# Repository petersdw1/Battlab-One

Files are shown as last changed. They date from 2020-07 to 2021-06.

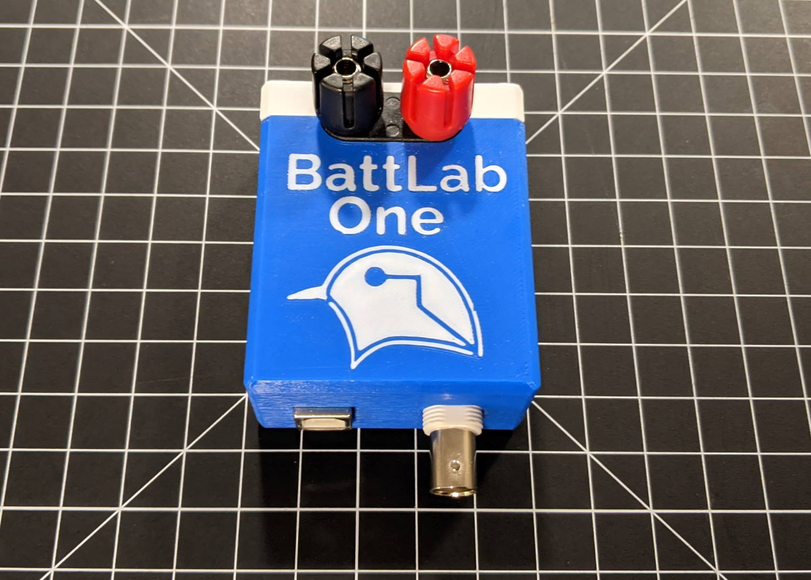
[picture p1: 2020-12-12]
3D_Printable_Enclosure/BattLab_One_Enclosure.jpg

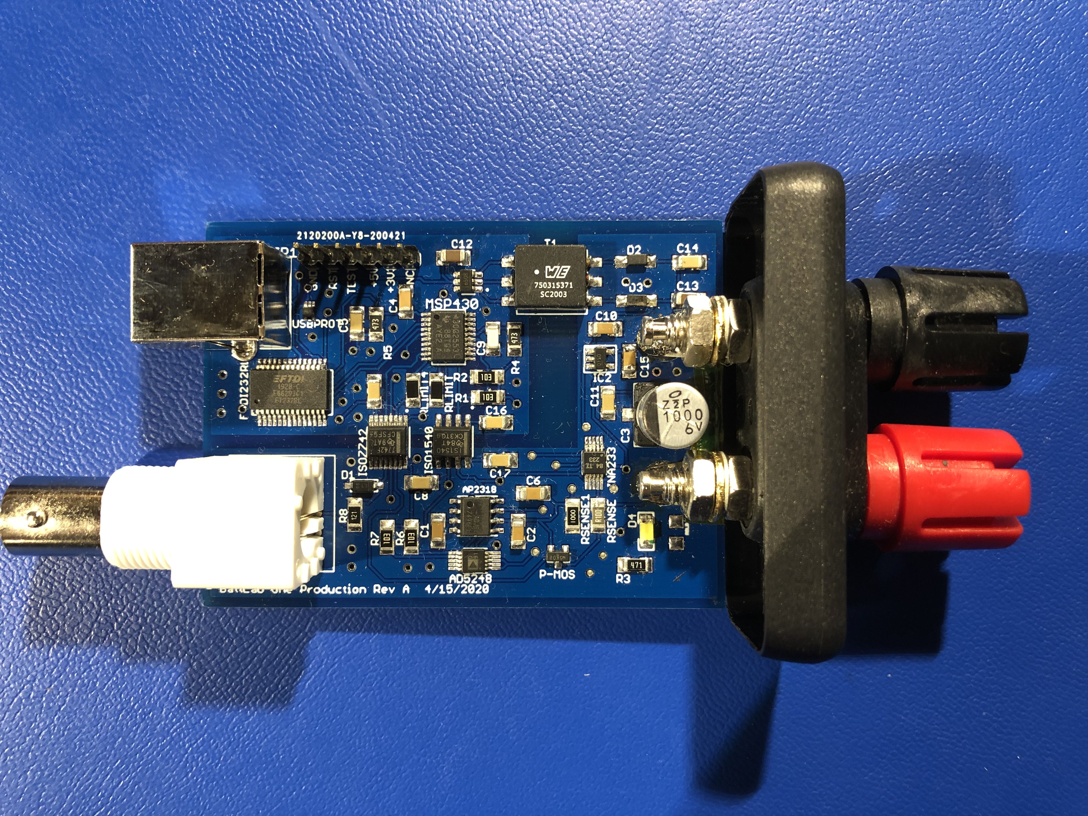
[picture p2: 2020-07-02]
Production_Rev_A_Board_Image.jpg

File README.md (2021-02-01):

# BattLab-One
A New Tool for Estimating and Optimizing Battery Life for Your Next Internet of Things Project

  - Battlab-One Quick Start Guide

  - BattLab_One_Production_Rev_A.py - Python Application Code for Production version 1.01

  - Production_Rev_A.sch - Schematic in Eagle

  - Production_Rev_A..brd - PCB Layout in Eagle

  - MSP430Firmware.c - Firmware code for the MSP430 for Production Version 1.01

  - BOM_Production_Rev_A - Bill of Materials for Battlab-One Production Rev A

  - 98-bluebird-labs.rules - Linux udev rules for Battlab-One

  See more at www.bluebird-labs.com
  
  

# Development

This project uses pipenv to take care of setting up a virtual environment as well as managing the dependencies needed.

1. Install pipenv as describe here https://pypi.org/project/pipenv/
2. Start a terminal and change to the root folder of this project.
3. Run pipenv to setup the environment: `pipenv install --dev`
4. Start the pipenv shell: `pipenv shell`
5. Start the application: `python BattLab_One_V1.0.6.py`

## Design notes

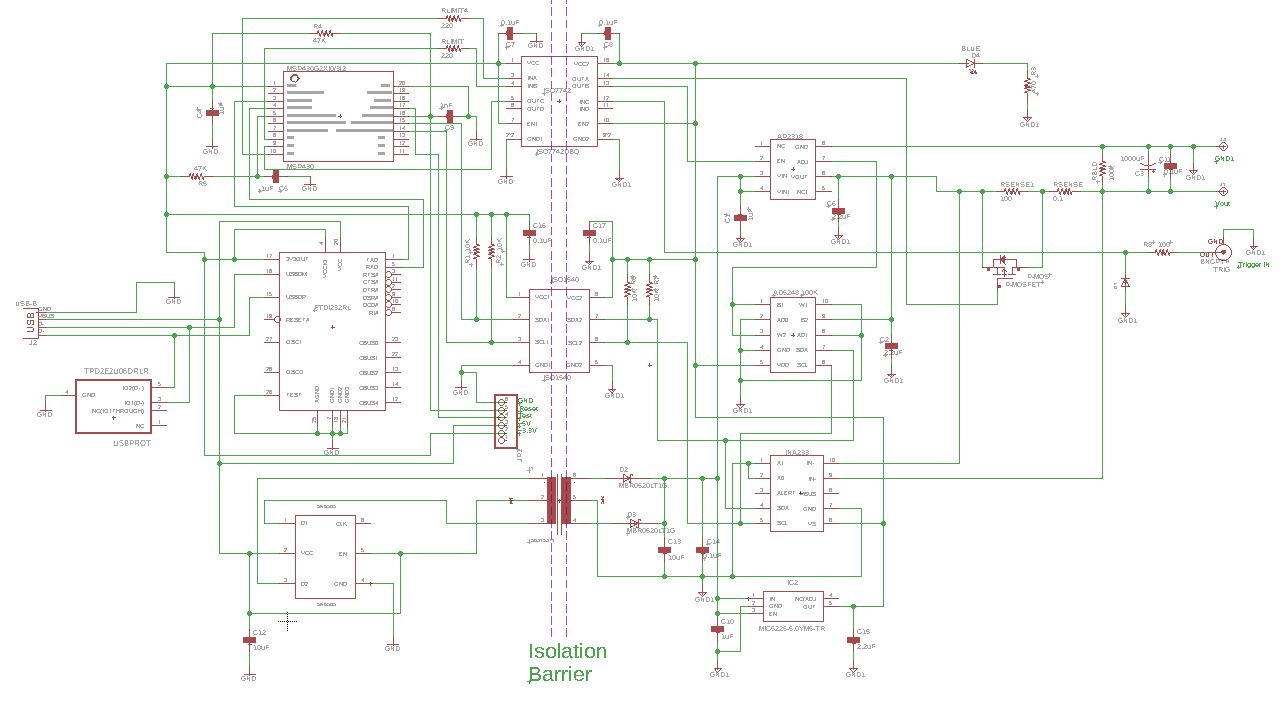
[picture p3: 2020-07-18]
Battlab_One_Schematic_Image.JPG

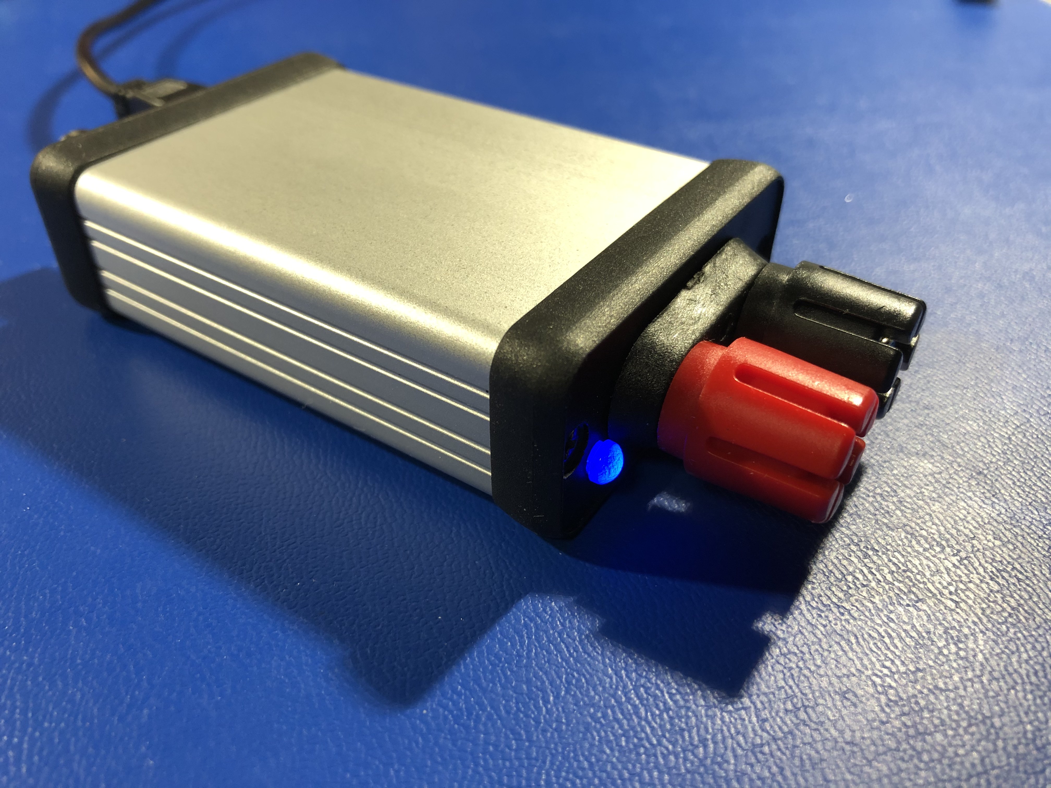
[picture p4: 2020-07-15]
Battlab_One.jpg

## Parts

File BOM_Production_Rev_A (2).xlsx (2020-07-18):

Part | Value | Device | Package | Description
AD5248 | 100K | AD5248 | MSOP-10 | Digital potentiometer
AP2318 |  | AP2318 | SOIC-8 | Voltage Regulator
C1 | 1uF | CAP1206 | 1206 | Capacitor
C2 | 2.2uF | CAP1206 | 1206 | Capacitor
C3 | 1000uF | CPOL-USF | PANASONIC_F | POLARIZED CAPACITOR
C4 | 1uF | CAP1206 | 1206 | Capacitor
C5 | .1uF | CAP1206 | 1206 | Capacitor
C6 | 2.2uF | CAP1206 | 1206 | Capacitor
C7 | 0.1uF | CAP1206 | 1206 | Capacitor
C8 | 0.1uF | CAP1206 | 1206 | Capacitor
C9 | 1nF | CAP1206 | 1206 | Capacitor
C10 | 1uF | CAP1206 | 1206 | Capacitor
C11 | 0.1uF | CAP1206 | 1206 | Capacitor
C12 | 10uF | CAP1206 | 1206 | Capacitor
C13 | 10uF | CAP1206 | 1206 | Capacitor
C14 | 0.1uF | CAP1206 | 1206 | Capacitor
C15 | 2.2uF | CAP1206 | 1206 | Capacitor
C16 | 0.1uF | CAP1206 | 1206 | Capacitor
C17 | 0.1uF | CAP1206 | 1206 | Capacitor
D1 |  | DIODESOD-123 | SOD-123 | Diode
D2 | MBR0520LT1G | MBR0520LT1G | SOD3716X117(SOD-123) | Surface Mount Schottky Power Rectifier Plastic SODâˆ’123 Package
D3 | MBR0520LT1G | MBR0520LT1G | SOD3716X117(SOD-123) | Surface Mount Schottky Power Rectifier Plastic SODâˆ’123 Package
D4 | BLUE | LED-BLUE1206 | LED-1206 | Blue LEDs for production use
FTDI232RL |  | FT232RL | SSOP28DB | USB UART
IC2 | MIC5225-5.0YM5-TR | MIC5225-5.0YM5-TR | SOT95P280X130-5N | MICROCHIP - MIC5225-5.0YM5-TR - LDO VOLT REG
INA233 |  | INA233 | VSSOP-10 | Texas Instruments current measurement
ISO1540 | ISO1540 | ISO1540 | SOIC127P600X175-8N | i2c Isolation
ISO7742 | ISO7742DBQ | ISO7742DBQ | SOP63P599X175-16N | High-Efficiency
J1 |  | BANANA_CONN | BANANA_CONN | Through-hole banana jack
J2 | USB-B | USBPTH | USB-B-PTH | USB Connectors
J3 |  | BANANA_CONN | BANANA_CONN | Through-hole banana jack
JP1 |  | PINHD-1X6 | 1X06 | PIN HEADER
MSP430 | MSP430 | G2X[0/3]2---PW20 | PW20 | MSP430G2X[0/3]2
P-MOS | P-MOSFET | P-CHANNEL-MOSFET | SOT23-3 | P-Channel MOSFET Mode Field Effect Transistor
R1 | 10K | RESISTOR1206 | 1206 | Resistor
R2 | 10K | RESISTOR1206 | 1206 | Resistor
R3 | 470 | RESISTOR1206 | 1206 | Resistor
R4 | 47K | RESISTOR1206 | 1206 | Resistor
R5 | 47K | RESISTOR1206 | 1206 | Resistor
R6 | 10K | RESISTOR1206 | 1206 | Resistor
R7 | 10K | RESISTOR1206 | 1206 | Resistor
R8 | 100 | RESISTOR1206 | 1206 | Resistor
RBLD | 100k | RESISTOR1206 | 1206 | Resistor
RLIMIT | 220 | RESISTOR1206 | 1206 | Resistor
RLIMIT4 | 220 | RESISTOR1206 | 1206 | Resistor
RSENSE | 0.1 | RESISTOR1206 | 1206 | Resistor
RSENSE1 | 100 | RESISTOR1206 | 1206 | Resistor
SN6505 | SN6505 | SN6505 | SOT95P280X145-6N | DC-DC Driver
T1 | 750315371 | 750315371 | TOR-6P-HT4_SMT_6PIN_(1201) | Transformer 1.1:1
TRIG | BNCPTH | BNCPTH | BNC | BNC Connector
USBPROT | TPD2E2U06DRLR | TPD2E2U06DRLR | SOT50P160X60-5N | LOW-CAPACITANCE 2-CHANNEL Â±25kv contact and +/-30kv air gap protection for USB2.0

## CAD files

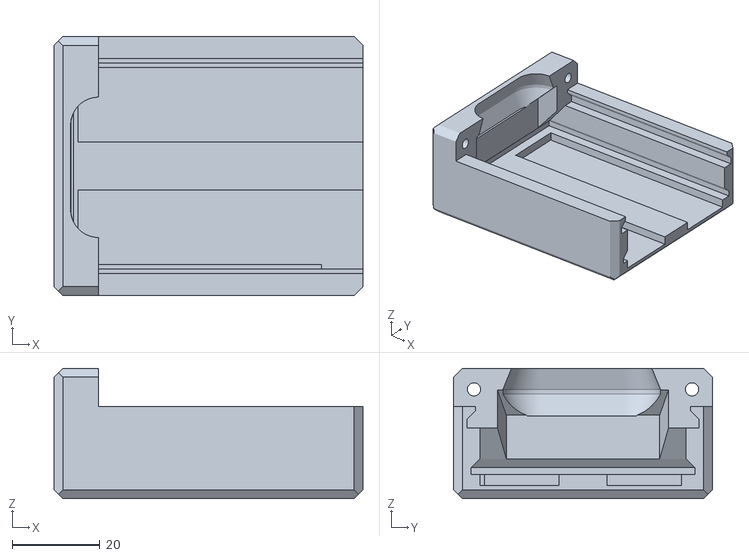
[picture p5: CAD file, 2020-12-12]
3D_Printable_Enclosure/BattLab_One_Enclosure_bottom.stl
70.5 x 59.0 x 29.8

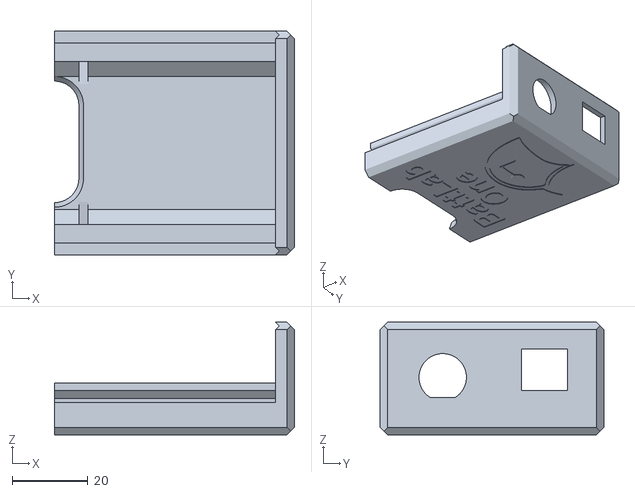
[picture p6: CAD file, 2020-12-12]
3D_Printable_Enclosure/BattLab_One_Enclosure_top-logo.stl
63.3 x 59.0 x 29.8

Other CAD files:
3D_Printable_Enclosure/BattLab_One_Enclosure_top.stl

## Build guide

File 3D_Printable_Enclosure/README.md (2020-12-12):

# 3D Printable Enclosure

This folder contains 3D printable STLs for the ["no enclosure" version of the BattLab-One](https://www.tindie.com/products/bbird/battlab-one-no-enclosure-includes-software/) available from Bluebird labs.  Two versions of the enclosure top model are provided, one with the BattLab One logo and one without.

## Model Files

* [Enclosure Top](BattLab_One_Enclosure_top.stl)
* [Enclosure Top with BattLab One text and Bluebird Labs logo](BattLab_One_Enclosure_top-logo.stl)
* [Enclosure bottom](BattLab_One_Enclosure_bottom.stl)

## Assembly Notes

The enclosure is retained with 2x M3 countersunk screws between 20-30mm long.  You will also need two M3 nuts which will be inserted into retaining slots in the top model.  Use a flat-blade screwdriver to press-fit the nuts into the provided nut traps.

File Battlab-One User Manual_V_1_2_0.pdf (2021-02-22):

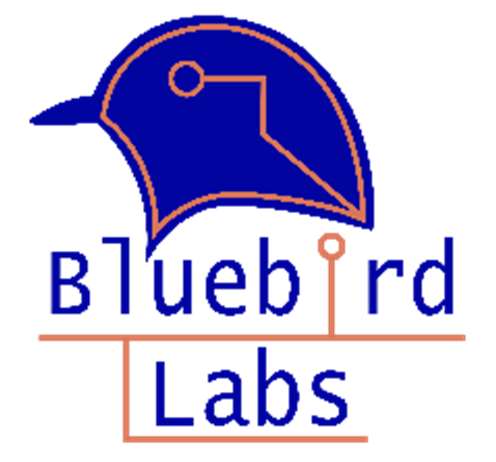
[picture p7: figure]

# BATTLAB-ONE USER MANUAL

A Better Way to Estimate Battery Life for IOT Projects

FEBRUARY 22, 2021
BLUEBIRD LABS LLC

Bluebird Labs LLC – BattLab-One Version 1.2.0 User Manual | 1

## THIS SOFTWARE IS PROVIDED BY THE COPYRIGHT HOLDERS AND

CONTRIBUTORS "AS IS"AND ANY EXPRESS OR IMPLIED WARRANTIES,

## INCLUDING, BUT NOT LIMITED TO, THE IMPLIED WARRANTIES OF MERCHANTABILITY AND FITNESS FOR A PARTICULARPURPOSE ARE DISCLAIMED. IN NO EVENT SHALL THE COPYRIGHT OWNER OR CONTRIBUTORS BE LIABLE FOR ANY DIRECT, INDIRECT, INCIDENTAL, SPECIAL, EXEMPLARY, OR

CONSEQUENTIAL | DAMAGES | (INCLUDING, | BUT | NOT | LIMITED
TO,PROCUREMENT OF SUBSTITUTE GOODS OR SERVICES; LOSS OF USE, DATA,

## OR PROFITS; OR BUSINESS INTERRUPTION) HOWEVER CAUSED AND ON ANY THEORY OF LIABILITY, WHETHER IN CONTRACT, STRICT LIABILITY, OR TORT (INCLUDING NEGLIGENCE OR OTHERWISE) ARISING IN ANY WAY OUT OF THE USE OF THIS SOFTWARE, EVEN IF ADVISED OF THE POSSIBILITY OF SUCH

DAMAGE.

Bluebird Labs LLC – BattLab-One Version 1.2.0 User Manual | 2

## Contents

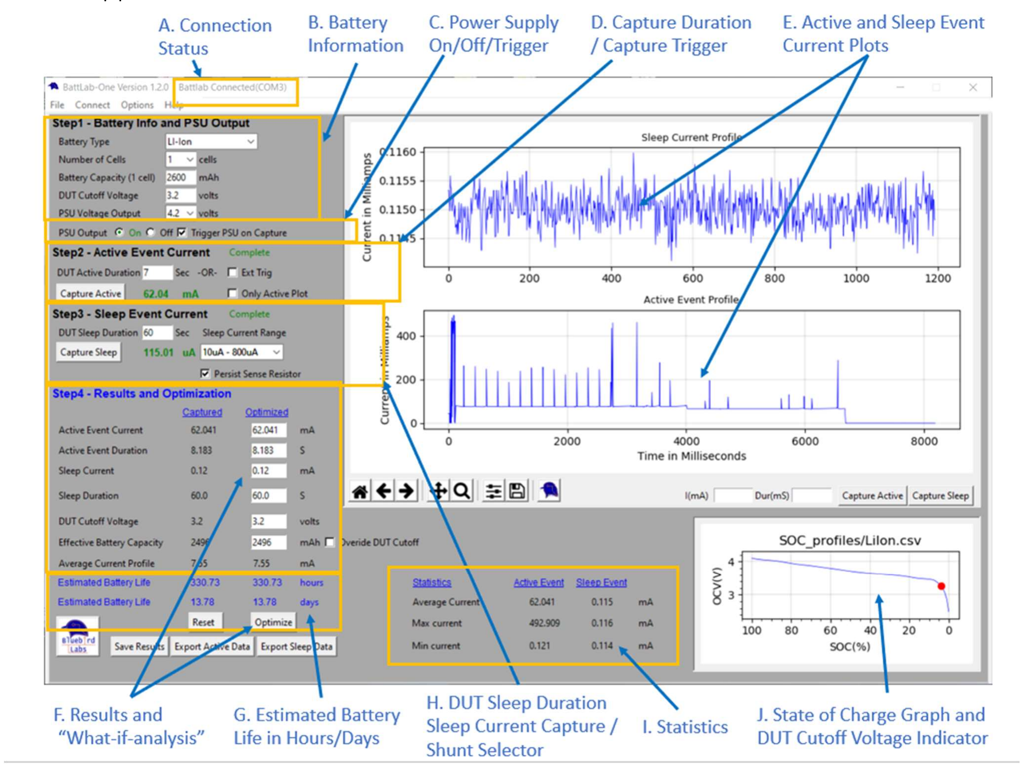
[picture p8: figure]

Bluebird Labs LLC – BattLab-One Version 1.2.0 User Manual | 3

## 1. BattLab-One Overview:

1.1.Application Software:

Figure 1. BattLab-One Application Software
A. Connection Status – Indicates the BattLab-One connection status
B. Battery Information section – User defined battery information
C. PSU control – PSU Manual ON/OFF control or Triggered ON by Capture Button
D. User entered active event duration or externally Triggered by DUT hardware
E. Active and sleep event current profile. Graphs of the sampled current for the DUT.
F. Displayed results of sampled current profile (active and sleep events) profile. “What-if” analysis data entry.
G. Estimated Battery life for both the captured and “what-if-analysis” data
H. DUT sleep duration and shunt resistor selector (10uA – 800uA or 800uA to 500mA).
I. Statistical information. Average max/min currents for active and sleep events.
J. State of Charge information with DUT Cutoff Voltage indicator

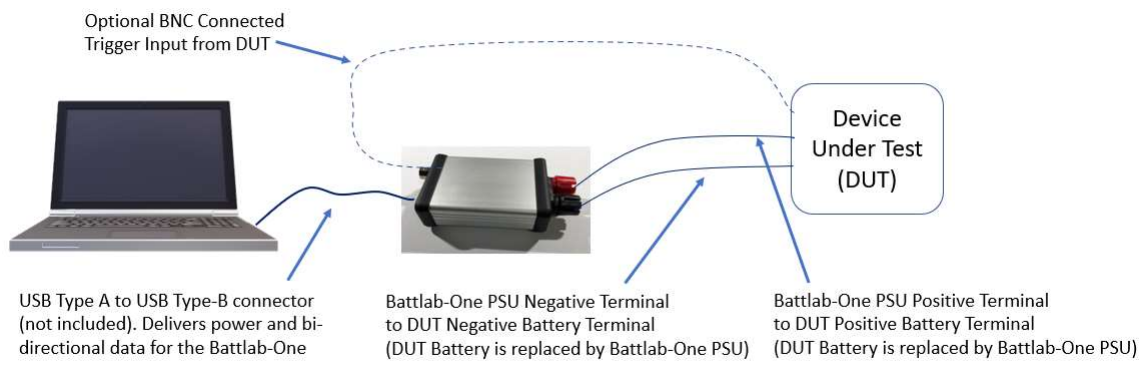
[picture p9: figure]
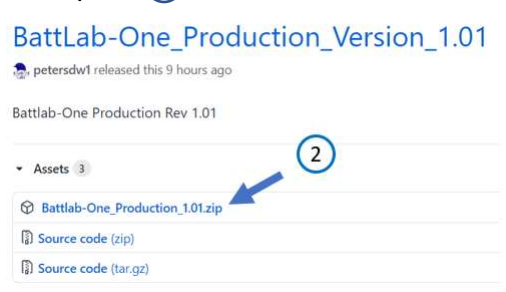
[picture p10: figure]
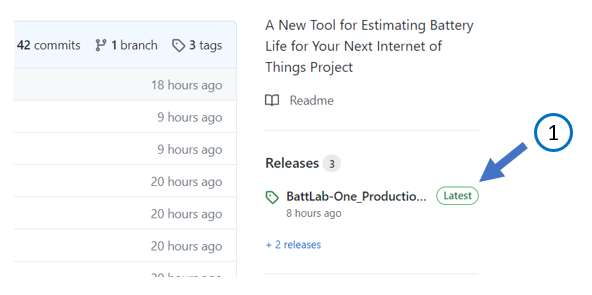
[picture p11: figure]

Bluebird Labs LLC – BattLab-One Version 1.2.0 User Manual | 4

1.2.Hardware Overview:

Figure 2. System Connections

NOTE: The BattLab-One is USB isolated from both data and power circuits.

NOTE: The BattLab-One Power Supply Unit (PSU) is capable of outputting up to 2 watts with voltage settings for the most common battery types:
Voltage Setting: 1.2V, 1.5V, 2.4V, 3.0V, 3.2V, 3.6V, 3.7V, 4.2V, 4.5V
Current: up to 450mA
Max Power: ~ 2.0 Watts

## 2. Getting Started

The executable for the BattLab-One application software can be found here: https://github.com/petersdw1/BattLab-One
Look for the Latest Release 1 and click on the Zip file 2 :

Once you’ve downloaded the Zip file, un-compress it to the location you choose. The BattLab-One application is the .exe file shown below. The un-compressed folder should look like this:

Bluebird Labs LLC – BattLab-One Version 1.2.0 User Manual | 5

NOTE: The SOC_profiles folder must be present and contain the State of Charge (SOC) .csv files for the batteries you intend to use. Bluebird Labs will be updating these from time to time, so please check the website for newer profiles at www.bluebird-labs.com.

Plug in your BattLab-One using a Type-A to Type-B USB cable and launch the BattLab-One executable. Once the software is running, you should see the connection status and COM port that your Windows device chose for the connection as shown below in the title bar of the main window (Figure 1:A).

If you forget to connect your BattLab-One with the USB cable you will see this:

To get connected:

### 1. Connect your BattLab-One to your computer with a Type-A to Type-B USB cable 2. Open the Connect menu and choose Select COM from the drop down 3. Click the Refresh Button

4. You should see a new COM port listed in the drop-down menu (usually the last one in the list)
5. Click the Connect button. You should now see the connected status and COM port as shown above.
6. Click Okay button.

Congratulations!
You are now ready to start estimating battery life for your IOT projects.

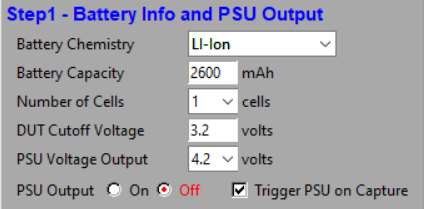
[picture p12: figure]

Bluebird Labs LLC – BattLab-One Version 1.2.0 User Manual | 6

## 3. Capturing Current Profiles

### 3.1 Enter Battery Information

The first step in the process is to enter the battery information you intend to use for your product or project. Selecting the Battery Chemistry drop down will default in values for all other data entry fields, but you can override any of them for your particular battery.

Once you’ve entered your battery information you can either turn ON the PSU output to power your device, or you can have the PSU output turned on after the Capture Active button is pressed in Step 2 below.
This option can be useful when your DUT does not have a power switch. Essentially, you’re using the BattLab-One to power on and off your DUT device.
To turn on the PSU output now, you must first uncheck the Trigger PSU on Capture checkbox as shown below and then click the ON radio button for the PSU output. Notice that the PSU Output ON text is green.

If you would like to trigger the output of the PSU when you click the Capture Active button in Step 2, then you should check the Trigger PSU on Capture checkbox and then click the ON radio button for the PSU output. Notice that the PSU Output Off text is still red. It should look as shown below:

Bluebird Labs LLC – BattLab-One Version 1.2.0 User Manual | 7

### 3.2 Capture Active Event Duration and Average Active Current

Now it’s time to capture the active event duration and current of your DUT. The active event is defined as the combined set of processor activities that occur after your device wakes up from sleep mode. Typical states involved with your active event include reading sensors, processing data, transmitting and receiving data, etc. before going back to sleep mode.
There are 2 ways to capture the active event duration: User Entered or Triggered.

### 3.2.1 User Entered Active Event Duration

The first is by entering in the number of seconds into the Capture Duration field. If you know your active state duration of your device (3 seconds in the example below) this is the quickest method.
After entering the number of seconds for data capture, click on the Capture Active button. Your device should now be powered and executing in its active mode. Once complete, the captured average current of your active event should be displayed in green text as shown:

### 3.2.2 Triggered Active Event Duration

The second method for setting the capture duration is to use the External Trigger on the BattLab-One (BNC connector on the back of the BattLab-One).
For triggering, you will need an external voltage source that can deliver between 3 to 5 volts. This can be from a DUT microprocessor pin or any other external source capable of delivering 3-5 volts. The BattLab-One will start capturing data on the rising edge of the 3 to 5 volt input. The BattLab-One will stop capturing data on the 3 to 5 volt falling edge.
To arm the BattLab-One for triggering, first check the Ext Trig checkbox. This will replace the text in the Capture Active button to now display ARM Trigger. Click the ARM Trigger button and the BattLab-One will now wait for a rising edge of 3-5 volts to start capturing data. Data capture will stop on a falling edge of 3-5 volts. Make sure you’ve connected the BNC cable for triggering.

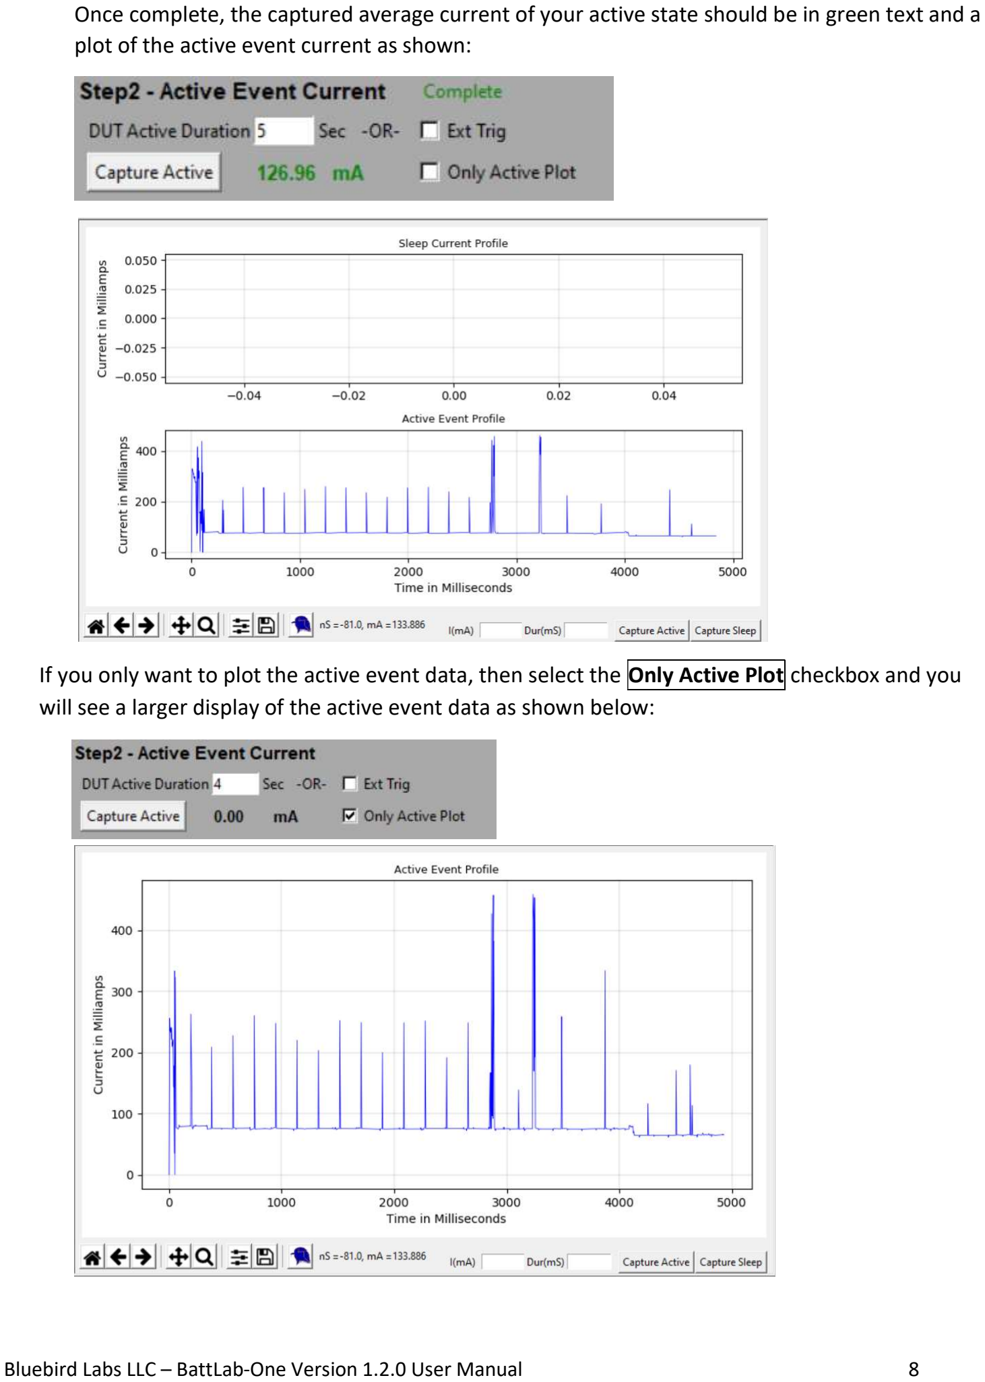
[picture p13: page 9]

Bluebird Labs LLC – BattLab-One Version 1.2.0 User Manual | 8

Once complete, the captured average current of your active state should be in green text and a plot of the active event current as shown:

If you only want to plot the active event data, then select the Only Active Plot checkbox and you will see a larger display of the active event data as shown below:

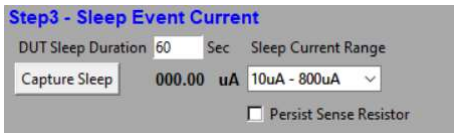
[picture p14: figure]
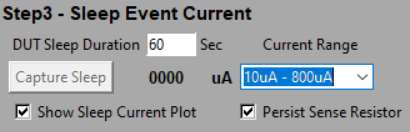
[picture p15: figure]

Bluebird Labs LLC – BattLab-One Version 1.2.0 User Manual | 9

### 3.3. Capture Sleep Duration and Sleep Current

Once the active state capture of your device is completed (in Step 3.2 above) you can now capture the sleep duration and sleep current of your device.
Sleep duration is defined as the sleep mode duration between your active mode events. Sleep duration is captured by entering the time you have selected for your DUT’s sleep mode duration. Enter that value in seconds into the DUT Sleep Duration field as shown below (e.g. 60 seconds)

Next, select the appropriate current range you expect your sleep current to be within by selecting either the 800uA-500mA or 10uA-800uA range selectors. By selecting these ranges, the BattLab-One will switch the appropriate shunt resistor for data capture mode.

NOTE: If you do not know your expected range, select the 800uA – 500mA range. If the actual sleep current falls below this range then BattLab-One will pop up a message and recommend the 10uA-800uA range. Selecting the 10uA-800uA range may damage the BattLab-One shunt resistor if the power output of your sleep mode state is greater than 1 Watt (e.g. 4.5 volt PSU output x 225mA sleep current = 1.01 watts).
Checking the Persist Sense Resistor box keeps the selected sense resistor turned on after sleep event capture. Use this option unchecked to have the BattLab-One switch back to the high current sense resistor so your DUT can continue functioning. Checking this box would leave the low current sense resistor (100 ohm) turned on and might affect your DUT from functioning once it comes out of sleep mode due to burden voltage.

Once you’ve entered the sleep duration, selected the appropriate sleep current range, and selected any additional options, click the Capture Sleep button. You should see your average sleep current

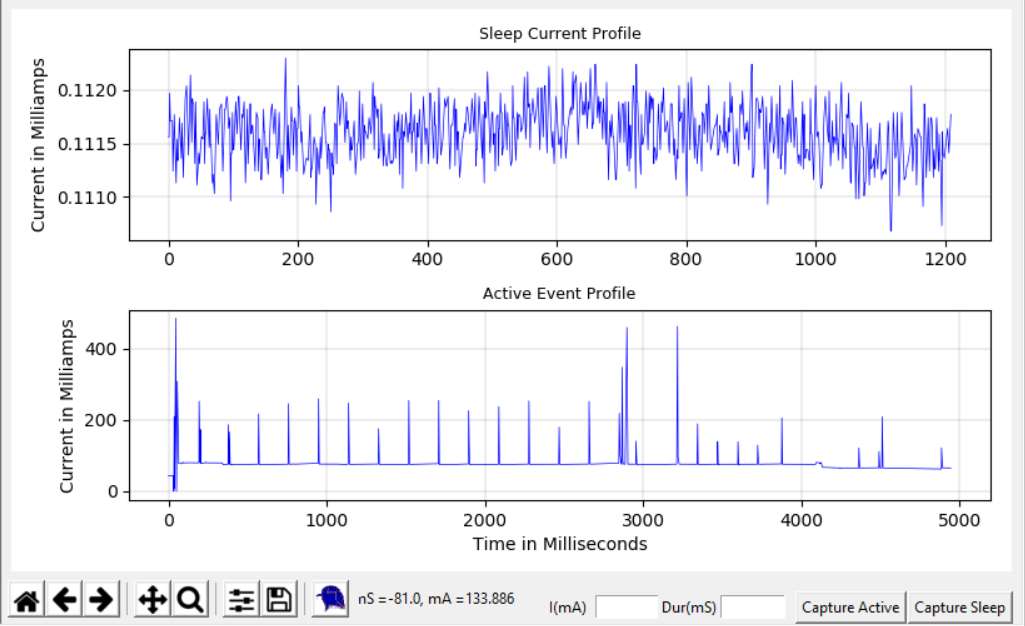
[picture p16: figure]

Bluebird Labs LLC – BattLab-One Version 1.2.0 User Manual | 10

displayed in green as shown below and a display of the sleep current plot above the Active Current plot if you have not selected the Only Active Plot box.

## 4. Results and What if Analysis

After completing steps 3.2 and 3.3 above, you should now see the statistics, results of your DUT device, and the battery life estimation as shown below. The Captured data is shown in the first column. The second Optimized column allows you to enter new values and to calculate new optimized Battery Life expectations by clicking on the Optimize button.

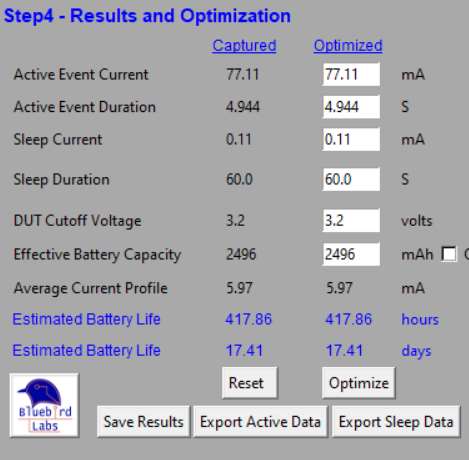
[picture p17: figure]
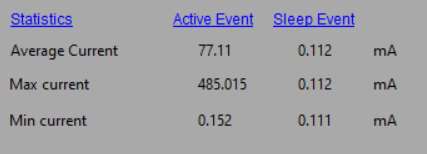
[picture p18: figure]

Bluebird Labs LLC – BattLab-One Version 1.2.0 User Manual | 11

The BattLab-One calculates the Effective Battery Capacity using the DUT Cutoff voltage and the Battery type data entered in Step 1. By checking the Override DUT Cutoff checkbox you can enter any value for the Effective Battery Capacity.

## 5. Working with the Current Plot Tools

After capturing the active event current in step 3.2 above, the Active event Current Profile Plot will be displayed (Figure 1: E). The graph has several features for working with the plot as shown below:

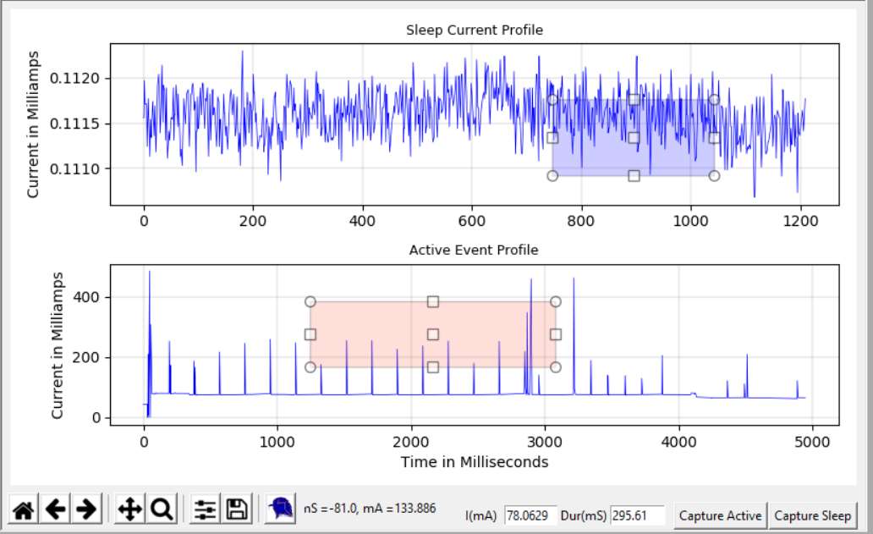
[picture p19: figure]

Bluebird Labs LLC – BattLab-One Version 1.2.0 User Manual | 12

Reset original view

Back to previous view

Forward to next view

Pan axes with left mouse, zoom with right

Zoom to rectangle

Configure subplots – NOT USED in this version of BattLab-One

Save the figure

Capture current ranges directly from the Active and Sleep current plots

The capture current range tool can be used to select ranges of data directly from the Active and Sleep plots. Clicking the Bluebird logo will activate a range selector on the plots as shown:

Note that the current I(mA) and duration Dur(mS) fields are automatically updated with the selected range values. Clicking the Capture Active or Capture Sleep buttons will replace the values in the Optimized column for further “what-if” analysis.

## 6. The State of Charge Graph

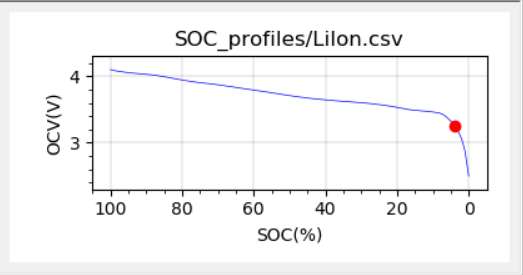
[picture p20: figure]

Bluebird Labs LLC – BattLab-One Version 1.2.0 User Manual | 13

The State of Charge Graph is displayed and updated based on the selected battery information as shown. The graph is meant to provide an indicator of the Open Circuit Voltage vs. State of Charge for a given battery chemistry. The BattLab-One uses this data, the user entered battery capacity (manufacturer’s stated mAh) and the entered DUT Cutoff Voltage to determine an estimated actual battery capacity. The graph indicates the DUT Cutoff voltage with a red dot as shown below.

Sate of Charge Graph

NOTE: The SOC_profiles folder must be present in the working directory where the BattLab-One executable file resides and must contain the State of Charge (SOC) .csv files for the batteries you intend to use. Bluebird Labs will be updating these from time to time so please check the website for newer profiles at www.bluebird-labs.com.

## 7. Options and Menus

The BattLab-One has several other Menus and Options. There is a Reset button that if clicked, will restore the original state of the BattLab-One. Only use the Reset button if you want to discard your current data. To save a BattLab-One profile, you can either click on the Save Results button or use the File/Save dropdown in the menu. To open a saved profile, you can use the File/Open dropdown in the menu.

Under the Options menu, there are several selections that users can make:

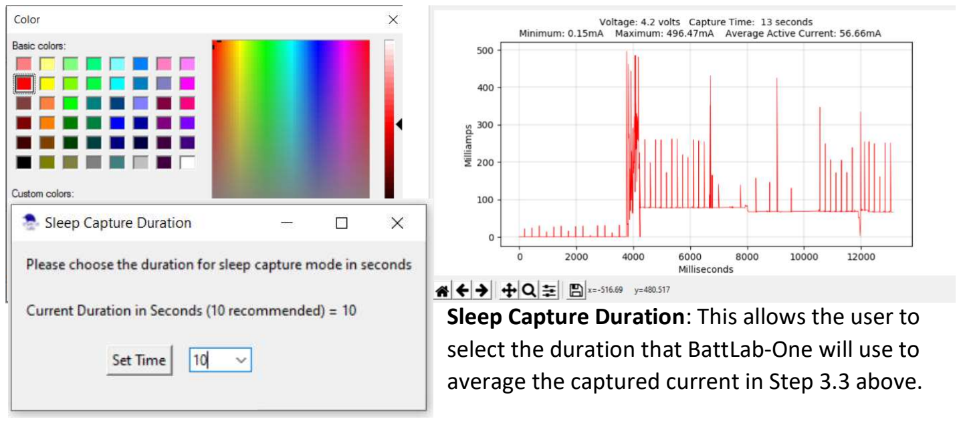
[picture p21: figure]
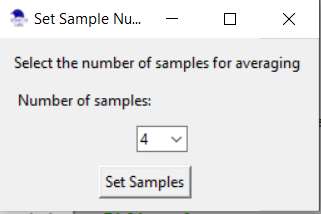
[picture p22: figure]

Bluebird Labs LLC – BattLab-One Version 1.2.0 User Manual | 14

Line Color: This will select the line color for the Active Event Profile Plot

Sleep Capture Duration: This allows the user to select the duration that BattLab-One will use to average the captured current in Step 3.3 above.

Select number averages per sample: This allows the user to select how many samples will be collected for the ADC to sample on data capture. The default is 4, but users can select 16 or 64. Be aware that selecting larger averaging sampls will reduce the reolution of the data capture. However, the increased sample rates can help in noisy DUT environments.

Help Menu: The Help/About menu will provide the BattLab-One and the Firmware version numbers as well as a url for support. Support can also be reached by clicking the Bluebird Labs logo in the bottom left corner of the screen. This will take you to the Bluebird Labs website where you can click on the Support page to enter any questions.

Exporting Data:

Bluebird Labs LLC – BattLab-One Version 1.2.0 User Manual | 15

Data can be exported using the Export Active Data and Export Sleep Data buttons shown under the results. You may also save only the results only (battery life and selections for profile) by clicking the Save Results button. These options are also avaialble in the File dropdown menu.

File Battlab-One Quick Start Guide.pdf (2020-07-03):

## Battlab-One Quick Start Manual

Thank you for purchasing the Battlab-One! This guide should help you find the necessary software and support for your new Battlab-One.
The executable application software can be found on my Github site here: https://github.com/petersdw1/BattLab-One

### 1. Look for the Latest Release and click on the Zip file:

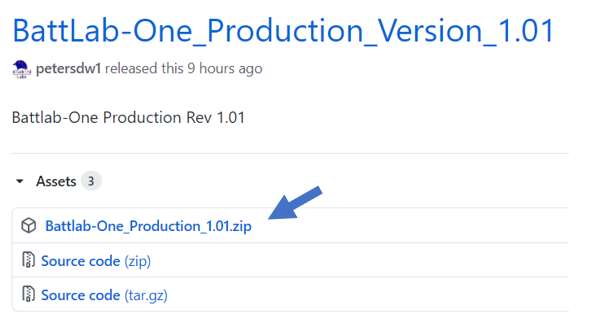
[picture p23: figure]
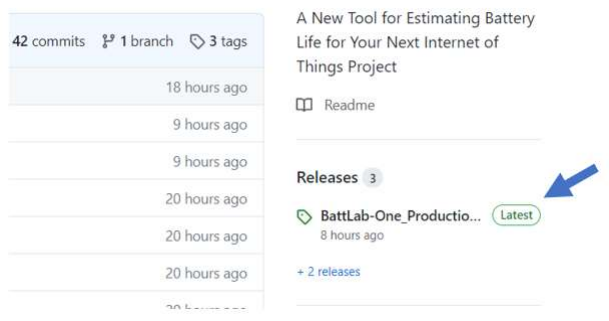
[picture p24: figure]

2. Once you’ve downloaded the Zip file, un-compress it to the location you choose. The Battlab-One application is the .exe file. The un-compressed folder should look like this:

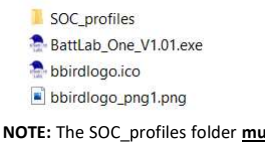
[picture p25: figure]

NOTE: The SOC_profiles folder must be present and contain the State of Charge (SOC) .csv files for the batteries you intend to use. Bluebird Labs will be updating these from time to time so please check the website for newer profiles at www.bluebird-labs.com.

### 3. Plug in your Battlab-One hardware using a Type-C to Type-B USB cable and launch

the Battlab-One executable. You should see the connection status and COM port that your Windows device chose for the connection as shown below.

If you forget to connect your Battlab-One with the USB cable you will see this:

To get connected:

### 1. Connect your Battlab-One to your computer with a Type-C to Type-B USB cable 2. Click the Refresh Button 3. You should see a new COM port listed in the drop-down menu (usually the last

one in the list)

### 4. Click the Connect button. You should now see the green connected status and

COM port as shown above.

You are now ready to start estimating battery life for your IOT projects!
Should you need support, you can submit issues/questions on the support link below. https://bluebird-labs.com/support/

Thank you again for purchasing the Battlab-One and enjoy!

Doug Peters
Bluebird Labs LLC
www.bluebird-labs.com

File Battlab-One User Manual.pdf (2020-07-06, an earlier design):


# BATTLAB-ONE USER MANUAL

A Better Way To Estimate Battery Life for IOT Projects

JUNE 1, 2020
BLUEBIRD LABS LLC

Bluebird Labs LLC - Battlab-One Version 1.01 User Manual

## THIS SOFTWARE IS PROVIDED BY THE COPYRIGHT HOLDERS AND

CONTRIBUTORS "AS IS"AND ANY EXPRESS OR IMPLIED WARRANTIES,

## INCLUDING, BUT NOT LIMITED TO, THE IMPLIED WARRANTIES OF MERCHANTABILITY AND FITNESS FOR A PARTICULARPURPOSE ARE DISCLAIMED. IN NO EVENT SHALL THE COPYRIGHT OWNER OR CONTRIBUTORS BE LIABLE FOR ANY DIRECT, INDIRECT, INCIDENTAL, SPECIAL, EXEMPLARY, OR

CONSEQUENTIAL | DAMAGES | (INCLUDING, | BUT | NOT | LIMITED
TO,PROCUREMENT OF SUBSTITUTE GOODS OR SERVICES; LOSS OF USE, DATA,

## OR PROFITS; OR BUSINESS INTERRUPTION) HOWEVER CAUSED AND ON ANY THEORY OF LIABILITY, WHETHER IN CONTRACT, STRICT LIABILITY, OR TORT (INCLUDING NEGLIGENCE OR OTHERWISE) ARISING IN ANY WAY OUT OF THE USE OF THIS SOFTWARE, EVEN IF ADVISED OF THE POSSIBILITY OF SUCH

DAMAGE.

## Contents

## 1. Battlab-One Overview:

1.1.Application Software:

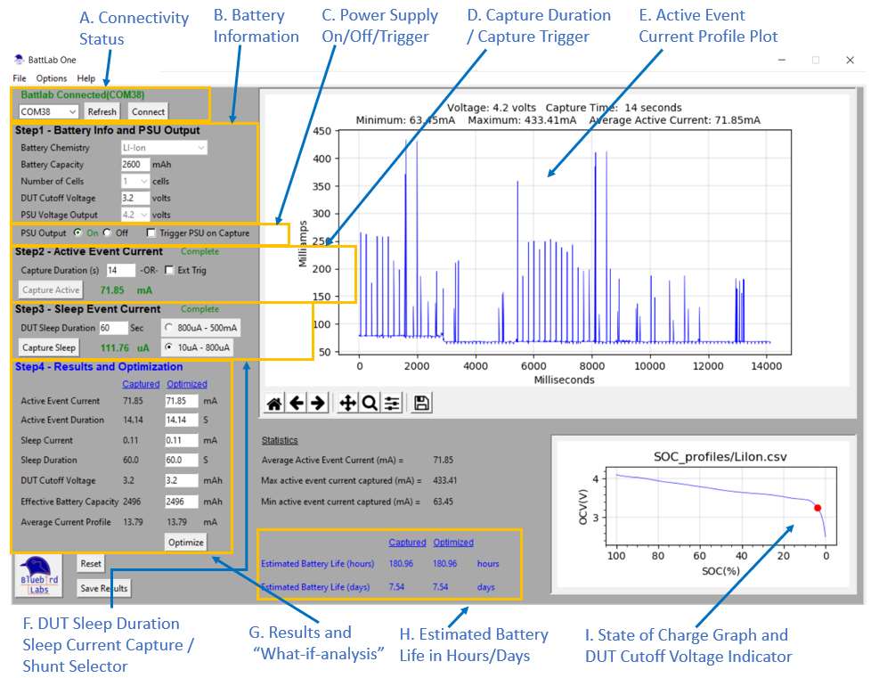
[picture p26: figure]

Figure 1. Battlab-One Application Software
A. Connectivity Status – Indicates the Battlab-One is connection status
B. Battery Information section – User defined battery information
C. PSU control – PSU Manual ON/OFF control or Triggered ON by Capture Button
D. User entered active event duration or externally Triggered by DUT hardware
E. Active event current profile. Graph of the sampled current for the DUT active event.
F. DUT sleep duration and shunt resistor selector (10uA – 800uA or 800uA to 500mA).
G. Displayed results of sampled current profile (active and sleep events) profile. “What-if”
H. Estimated Battery life for both the captured and “what-if-analysis” data.
I. State of Charge information with DUT Cutoff Voltage indicator from data supplied in item

1.2.Hardware Overview:

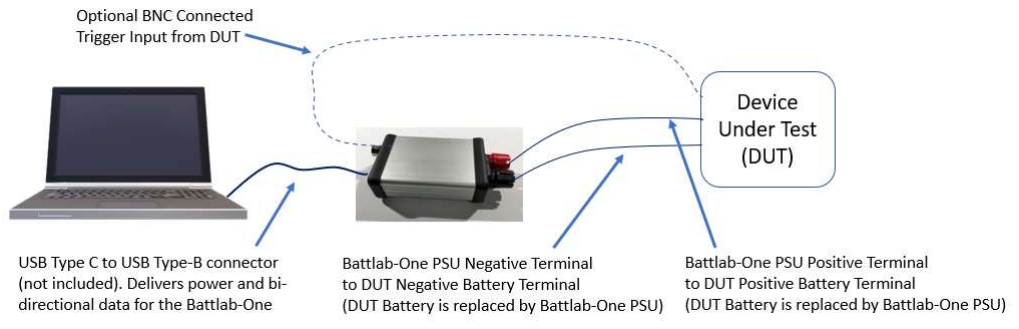
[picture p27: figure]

Figure 2. System Connections

NOTE: The Battlab-One is USB isolated from both data and power circuits.

NOTE: The Battlab-One Power Supply Unit (PSU) is capable of outputting up to 2 watts with voltage settings for the most common battery types:
Voltage Setting: 1.2V, 1.5V, 2.4V, 3.0V, 3.2V, 3.6V, 3.7V, 4.2V, 4.5V
Current: up to 450mA
Max Power: 2.0 Watts

## 2. Getting Started

The executable Battlab-One application software can be found here: https://github.com/petersdw1/BattLab-One
Look for the Latest Release 1 and click on the Zip file 2 :

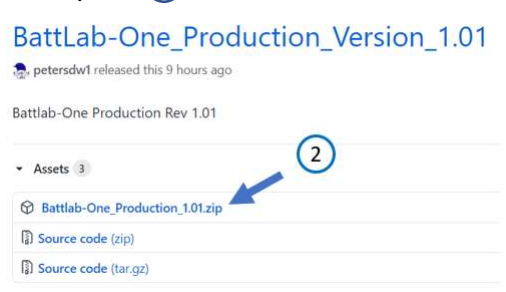
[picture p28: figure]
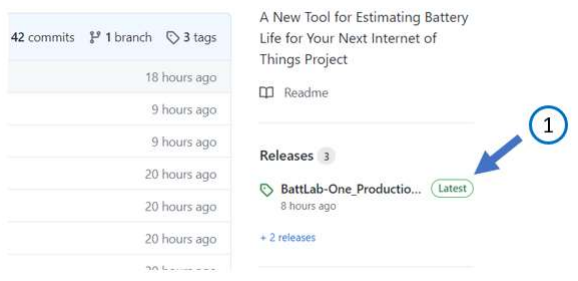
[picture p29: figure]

Once you’ve downloaded the Zip file, un-compress it to the location you choose. The Battlab-One application is the .exe file. The un-compressed folder should look like this:

NOTE: The SOC_profiles folder must be present and contain the State of Charge (SOC) .csv files for the batteries you intend to use. Bluebird Labs will be updating these from time to time so please check the website for newer profiles at www.bluebird-labs.com.

Plug in your Battlab-One hardware using a Type-C to Type-B USB cable and launch the Battlab-One executable. Once the software is running you should see the connection status and COM port that your Windows device chose for the connection as shown below in the upper left corner of the screen (Figure 1:A).

If you forget to connect your Battlab-One with the USB cable you will see this:

To get connected:

### 1. Connect your Battlab-One to your computer with a Type-C to Type-B USB cable 2. Click the Refresh Button

3. You should see a new COM port listed in the drop-down menu (usually the last one in the list)
4. Click the Connect button. You should now see the green connected status and COM port as shown above.

Congratulations!
You are now ready to start estimating battery life for your IOT projects.

## 3. Capturing Current Profiles

### 3.1 Enter Battery Information

The first step in the process is to enter the battery information you intend to use for your product or project. Selecting the Battery Chemistry drop down will default in values for all other data entry fields, but you can override any of them for your particular battery.


Once you’ve entered your battery information you can either turn ON the PSU output to power your device or you can have the PSU output turned ON after the Capture Active button is pressed in Step 2 below.
This option can be useful when your DUT does not have a power switch. Essentially, you’re using the Battlab-One to power on and off your DUT device.
To turn on the PSU output now, you must first uncheck the Trigger PSU on Capture checkbox as shown below and then click the ON radio button for the PSU output. Notice that the PSU Output ON text is green.

If you would like to trigger the output of the PSU when you click the Capture Active button in Step 2, the you should check the Trigger PSU on Capture checkbox and then click the ON radio button for the PSU output. Notice that the PSU Output Off text is now red . It should look as shown below:

### 3.2 Capture Active Event Duration and Average Active Current

Now its time to capture the active event duration and current of your DUT. The active event is defined as the combined set of processor activities that occur after your device wakes up from sleep mode. Typical states involved with your active event include reading sensors, processing data, transmitting and receiving data, etc. before going back to sleep mode.

There are 2 ways to capture the active event duration: User Entered or Triggered.

### 3.2.1 User Entered Active Event Duration

The first is by entering in the number of seconds into the Capture Duration field. If you know your active state duration of your device (13 seconds in the example below) this is the quickest method.
After entering the number of seconds for data capture, click on the Capture Active button. Your device should now be powered and executing in its active mode. Once complete, the captured average current of your active event should be displayed in green text as shown :

### 3.2.2 Triggered Active Event Duration

The second method for setting the capture duration is to use the External Trigger on the Battlab-One (BNC connector on the back of the Battlab-One).
For triggering, you will need an external voltage source that can deliver between 3 to 5 volts. This can be from a DUT microprocessor pin or any other external source capable of delivering 3-5 volts. The Battlab-One will start capturing data on the rising edge of the 3 to 5 volt input. The Battlab-One will stop capturing data on the 3 to 5 volt falling edge.
To arm the Battlab-One for triggering, first check the Ext Trig checkbox. This will replace the text in the Capture Active button to now display ARM Trigger. Click the ARM Trigger button and the Battlab-One will now wait for a rising edge of 3-5 volts to start capturing data. Data capture will stop on a falling edge of 3-5 volts. Make sure you’ve connected the BNC cable for triggering.

Once complete, the captured average current of your active state should be in green text as shown below.

### 3.3. Capture Sleep Duration and Sleep Current

Once the active state capture of your device is completed (in Step 3.2 above) you can now capture the sleep duration and sleep current of your device.
Sleep duration is defined as the sleep mode duration between your active mode events. Sleep duration is captured by entering the time you have selected for your DUT’s sleep mode duration. Enter that value in seconds into the DUT Sleep Duration field as shown below (e.g. 60 seconds)

Next, select the appropriate current range you expect your sleep current to be within by selecting either the 800uA-500mA or 10uA-800uA range selectors. By selecting these ranges, the Battlab-One will switch the appropriate shunt resistor for data capture mode.

NOTE: If you do not know your expected range, select the 800uA – 500mA range. If the actual sleep current falls below this range then Battlab-One will pop up a message and recommend the 10uA-800uA range. Selecting the 10uA-800uA range may damage the Battlab-One shunt resistor if the power output of your sleep mode state is greater than 1 Watt (e.g 4.5 volt PSU output x 225mA sleep current = 1.01 watts).
Once you’ve entered the sleep duration and selected the appropriate sleep current range, click the Capture Sleep button. You should see your sleep current displayed in green as shown below.

### 3.4 Results and What if Analysis

After completing steps 3.2 and 3.3 above, you should now see the statistics, results of your DUT device, and the battery life estimation as shown below. The Captured data is shown in the first column. The second Optimized column allows you to enter new values and to calculate new optimized Battery Life expectations by clicking on the Optimize button.

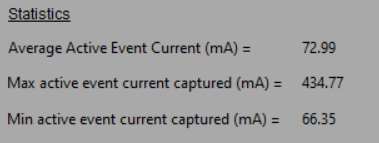
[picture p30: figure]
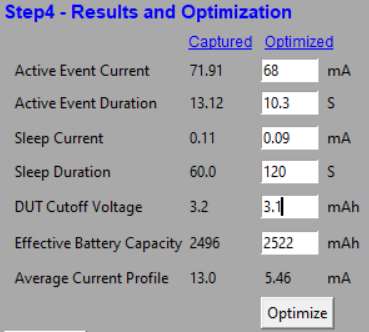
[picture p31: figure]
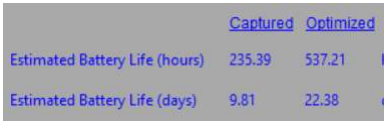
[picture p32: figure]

### 4. Working with the Active Event Current Plot Tools

After capturing the active event current in step 3.2 above, the Active event Current Profile Plot will be displayed (Figure 1:E). The graph has several features for working with the plot as shown below:

Reset original view

Back to previous view

Forward to next view

Pan axes with left mouse, zoom with right

Zoom to rectangle

Configure subplots – NOT USED in this version of Battlab-One

Save the figure

### 5. The State of Charge Graph

The State of Charge Graph is displayed and updated based on the selected battery information as shown. The graph is meant to provide an indicator of the Open Circuit Voltage vs. State of Charge for a given battery chemistry. The Battlab-One uses this data, the user entered battery capacity (manufacturer’s stated mAh) and the entered DUT Cutoff Voltage to determine an estimated actual battery capacity. The graph indicates the DUT Cutoff voltage with a red dot as shown below.
Sate of Charge Graph


NOTE: The SOC_profiles folder must be present in the working directory where the Battlab-One executable file resides and must contain the State of Charge (SOC) .csv files for the batteries you intend to use. Bluebird Labs will be updating these from time to time so please check the website for newer profiles at www.bluebird-labs.com.

### 6. Options and Menus

The Battlab-One has several other Menus and Options. First, there is a Reset button that if clicked, will restore the original state of the data capture. Only use the Reset button if you want to discard your current data. To save a Battlab-One profile, you can either click on the Save Results button or use the File/Save dropdown in the menu. To open a saved profile, you can use the File/Open dropdown in the menu.

Under the Options menu, there are several selections that users can make: Line Color: This will select the line color for the Active Event Profile Plot

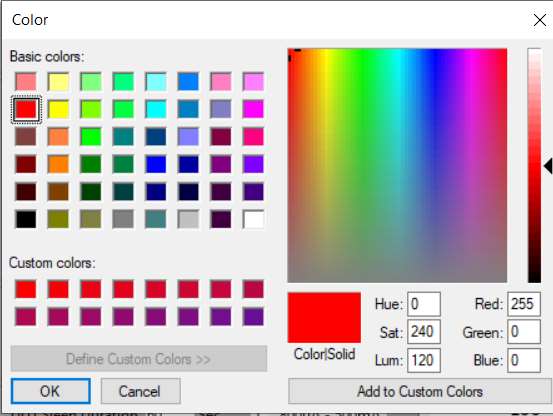
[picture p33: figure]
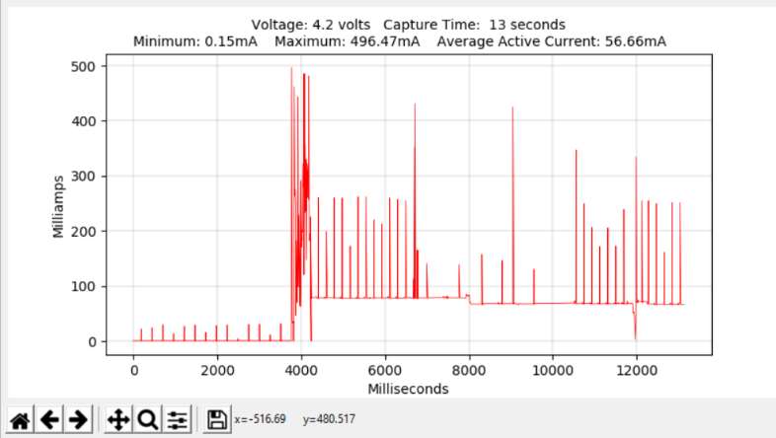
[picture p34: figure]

Sleep Capture Duration: This allows the user to select the duration that Battlab-One will use to average the captured current in Step 3.3 above.

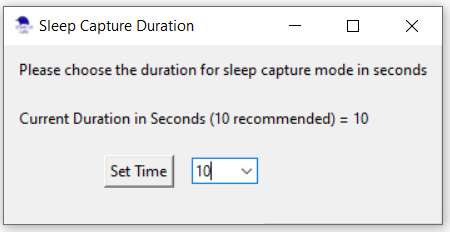
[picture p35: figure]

Select number averages per sample: This allows the user to select how many samples will be collected for the ADC to sample on data capture. The default is 4, but users can select 16 or 64. Be aware that selecting larger averaging sampls will reduce the reolution of the data capture. However, the increased sample rates can help in noisy DUT environments.


Help Menu: The Help/About menu will provide the Battlab-One and the Firmware version numbers as well as a url for support. Support can also be reached by clicking the Bluebird Labs logo in the bottom left corner of the screen. This will take you to the Bluebird Labs website where you can click on the Support page to enter any questions.

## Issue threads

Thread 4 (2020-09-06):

Missing Counts.

vangalvin, 2020-09-06:
I have been trying to pull the data out of the raw log and use that for creating power usage prifiles. Exporting the data in to a spreadsheet I noticed that the sample counts were not lining up.

For example
`219,0.04412
220,0.04412
222,0.02941
223,0.02941
224,0.04412`

notice 221 is missing, sampling over 60 seconds the csv had 60718 entries according to sample count however when imported in to a spreadsheet there were only 67992 entries meaning some of the data was missing.

I only discovered this when I was trying to work out how to convert the count in to time and create a chart based on peak usage over time.

For the above above example and thankfully in my case its on the sleep side of a sample however if this was to appear during the wake cycle this would throw off the figures dramaticaly.

petersdw1, 2020-09-06:
Good catch Boris. I do some software filtering of any noise from the INA233
and it probably is tossing the noise sample but not also tossing the count.
I can fix in the next release. Should be in about a week.

Doug

On Sat, Sep 5, 2020 at 7:09 PM Boris van Galvin <notifications@github.com>
wrote:

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

petersdw1, 2020-10-13:
Hi Boris, this should now be working properly in V1.0.9.  Can you test on your side and see if its working ok?

Closed 2020-10-19.

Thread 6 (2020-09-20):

// Capture Sleep Low Range //

salvagione, 2020-09-20:
After **Capture Active** AND when the _low range_ is selected for **Capture Sleep** the DUT cannot source the current needed for the next active event. Toggling back to the _high range_ after **Capture Sleep** is a work around. Possible solution, have the software toggle back to the _high range_ after the **Capture Sleep** is complete. BTW, great product.

petersdw1, 2020-09-22:
Great idea! I just published a new release, 1.0.7 that resets to the high current after sleep current is captured.

salvagione, 2020-09-24:
It's working for me. Thank you!

petersdw1, 2020-10-02:
Excellent thanks Paolo, are you ok if I close this open issue on my Github
site?

On Wed, Sep 23, 2020 at 7:03 PM Paolo Salvagione <notifications@github.com>
wrote:

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

--
Doug Peters
dpeters@bluebird-labs.com
www.bluebird-labs.com

salvagione, 2020-10-02:
Hello Doug,

I closed it a few days ago. Is it showing open on your end?

Best,
Paolo

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

petersdw1, 2020-10-02:
Oh sorry Paolo!  I am looking at the wrong issue.  How's everything working?

Doug

On Fri, Oct 2, 2020 at 11:37 AM Paolo Salvagione <notifications@github.com>
wrote:

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

--
Doug Peters
dpeters@bluebird-labs.com
www.bluebird-labs.com

salvagione, 2020-10-02:
I'm working code optimization and the [spurious readings](https://github.com/petersdw1/Battlab-One/issues/9) issue is challenging. I'm curious what happens to accuracy on sub 10uA readings? Can they be trusted or should I place a high value, precision resistor, in parallel with the DUT to pull the current back into range?

petersdw1, 2020-10-02:
I wouldn't trust anything below 10uA....I'd go the parallel resistor route

On Fri, Oct 2, 2020 at 12:43 PM Paolo Salvagione <notifications@github.com>
wrote:

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

--
Doug Peters
dpeters@bluebird-labs.com
www.bluebird-labs.com

petersdw1, 2020-10-12:
Hi Paolo,

I received the BattLab-One adapter.  Thank you very much!  Can I purchase a
few of these from you?  They could be very handy!

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

--
Doug Peters
dpeters@bluebird-labs.com
www.bluebird-labs.com

salvagione, 2020-10-12:
Hello Doug,

Happy to hear you like it. I've revised the design.
I've added strain relief for the battery connector. How many would you
like? I'll add to my next OSH Park order.

Best,
Paolo

On Mon, Oct 12, 2020 at 6:29 AM Doug Peters <notifications@github.com>
wrote:

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

petersdw1, 2020-10-12:
Thanks Paolo, how much $$ for 10?

On Mon, Oct 12, 2020 at 9:21 AM Paolo Salvagione <notifications@github.com>
wrote:

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

--
Doug Peters
dpeters@bluebird-labs.com
www.bluebird-labs.com

salvagione, 2020-10-12:
Can I get you the part numbers and you build them up yourself?

P

On Mon, Oct 12, 2020 at 7:26 AM Doug Peters <notifications@github.com>
wrote:

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

petersdw1, 2020-10-12:
Yes perfect thank you!

Any luck deciphering the spurious readings you were getting on the
BattLab-One?

How has the product performed for you to this point?

On Mon, Oct 12, 2020 at 9:38 AM Paolo Salvagione <notifications@github.com>
wrote:

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

--
Doug Peters
dpeters@bluebird-labs.com
www.bluebird-labs.com

salvagione, 2020-10-12:
Here's a link <https://oshpark.com/shared_projects/Mbv8RsNX> to the design
I sent you. Here's the link
<https://www.digikey.com/en/products/detail/adafruit-industries-llc/3814/9380221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>
for the battery cable and here's a link
<https://www.amazon.com/gp/product/B06XS79JT3/ref=ppx_yo_dt_b_search_asin_title?ie=UTF8&psc=1>
for the 4mm connectors. I'll send a link for the version with the strain
relief later today.

No luck with the spurious high readings. I'm ignoring them for now as I'm
mostly interested in the quiescent current.

So far I'm quite happy with the device and the software.

On Mon, Oct 12, 2020 at 7:46 AM Doug Peters <notifications@github.com>
wrote:

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

petersdw1, 2020-10-12:
Excellent thanks Paolo.  As always, if you have any problems please send it
my way.

If you are so inclined, would you mind writing a quick review of your
experience on the Tindie suite? (https://www.tindie.com/stores/bbird/). I
could use the reviews.

 If not, worries!

On Mon, Oct 12, 2020 at 10:11 AM Paolo Salvagione <notifications@github.com>
wrote:

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

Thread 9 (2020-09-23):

// Spurious Values //

salvagione, 2020-09-23:
During transmits I'm seeing values that are much higher then the LDO on the device can provide and don't show up on my DMM or PSU.

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

petersdw1, 2020-09-24:
This is either a true noise reading from the INA233 in which case increasing the number of samples to use for averaging might fix(see image below), or it's an artifact of the large 1000uF capacitor I have on the output (which I am thinking of removing in future designs).

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

Closed 2020-12-28.

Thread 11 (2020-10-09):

Problems with other FTDI adapters connected

electrokean, 2020-10-09:
I hit problems (hangs) with multiple FTDI adapters connected at startup, as the grep on list_ports selects the wrong one.  It assumes only a single VID:PID match, and thus tries to establish a connection to other equipment with no way to cancel.

I also hit an issue with one adapter that had a single digit serial number - this stopped me running the precompiled code.  I had to set up python dev environment to track down the failure.  I'll submit a simple PR to work around this.

electrokean, 2020-10-09:
Is there a reason (cross platform compatibilty) that you needed the grep on the port list?
https://github.com/petersdw1/Battlab-One/blob/e4eb4a6a05422b6fdc52cb1a21500bbca6068752/BattLab_One_V1_0_9.py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
Couldn't the line just be:
`com_port = p.device`

This plus PR https://github.com/petersdw1/Battlab-One/pull/12 fix my current issues starting the app on Windows.

electrokean, 2020-10-09:
Well I messed up my fork for PR #12
I have split it into two new PRs #13 and #14 instead

petersdw1, 2020-10-13:
Hi Kean, I merged your PR into release V1.0.9.  Can you test and see if its working for you now?

electrokean, 2020-10-21:
I've tested 1.0.9 and 1.1.0 and this works much better now.

Closed 2020-10-21.

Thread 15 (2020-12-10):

Error message: Failed to execute script BattLab_One_V1.1.1

aderusha, 2020-12-10:
Brand new user trying to get my new BattLab One running under Windows 10.  I've downloaded the most recent release v1.1.1, extracted the contents, and am attempting to launch "BattLab_One_V1.1.1.exe" from the root folder of the ZIP archive.  The result when launching is a dialog titled "Fatal error detected" with the text "Failed to execute script BattLab_One_V1.1.1".  Trying 1.1.0 yields the same result, launching as Administrator also produces the same error.

Let me know if there's any further information I can provide, I'm stuck at step one.

petersdw1, 2020-12-10:
Hi Allen,

Sorry to hear you are having issues.  Can you try a couple things for me?

1. Check to make sure your PC security software isn't blocking the app from
running
2. Unplug the BattLab-One and try executing the software

On Thu, Dec 10, 2020 at 9:44 AM Allen Derusha <notifications@github.com>
wrote:

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

--
Doug Peters
dpeters@bluebird-labs.com
www.bluebird-labs.com

aderusha, 2020-12-10:
The AV solution in play is Windows Defender (default Windows 10 solution from MS).  Threat history shows no actions or logs entries for the BattLab exe.  Disabling the service entirely doesn't change the result.  The behavior persists with the device plugged in or unplugged.

aderusha, 2020-12-10:
OK - just managed to get it to work.  Running the .exe from inside a PowerShell terminal session allows the application to launch as expected.  Double-clicking in explorer continues to return the error, so I cannot launch from an icon/shortcut etc but I can launch from a terminal.

Not ideal, but it works!

petersdw1, 2020-12-10:
Is the executable in the same directory with the *SOC_profiles *and *icons *
folders?

On Thu, Dec 10, 2020 at 10:42 AM Allen Derusha <notifications@github.com>
wrote:

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

--
Doug Peters
dpeters@bluebird-labs.com
www.bluebird-labs.com

aderusha, 2020-12-10:
Correct, it was a straight extract of the provided ZIP with the folders.  File structure looks like this:

```
D:\Download\BattLab-Release_V1.1.1\
├─ BattLab_One_V1.1.1.exe
│
├───icons
│       bbirdlogo.ico
│       bbirdlogo.xbm
│       bbirdlogo_png1.png
│
└───SOC_profiles
        AA_AAA.csv
        AA_AAA_2.csv
        AA_AAA_3.csv
        CR123.csv
        CR2032.csv
        LiFePO4.csv
        LiIon.csv
        NiMH_AA.csv
        NiMH_AAA.csv
        NiMH_AAA_2.csv
        NiMH_AAA_3.csv
        NiMH_AA_2.csv
        NiMH_AA_3.csv
```

petersdw1, 2020-12-10:
Ok Allen thanks. Glad it's working, but puzzled why it's not in Explorer.
I'll keep the issue open for now in my GitHub and see if anyone else has
seen a similar issue.

Doug

On Thu, Dec 10, 2020 at 10:49 AM Allen Derusha <notifications@github.com>
wrote:

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

--
Doug Peters
dpeters@bluebird-labs.com
www.bluebird-labs.com

Closed 2020-12-29.

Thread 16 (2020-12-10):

Binary firmware

sabas1080, 2020-12-10:
Hi @petersdw1

thanks for your work, i am making a version with USB C, do you have the binary firmware precompiled?

petersdw1, 2020-12-11:
Hi Saba, I’m working on on a USB C as well, seems like the next logical
step haha! I load the binaries onto the MSP430 using a TI Launchpad and
Code Composer.

Hope this helps!

Doug

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
--
Doug Peters
dpeters@bluebird-labs.com
www.bluebird-labs.com

sabas1080, 2020-12-11:
Excellent, I have done it

You can see our work in Kicad here: https://github.com/ElectronicCats/Battlab-One

Thanks for you work

petersdw1, 2020-12-11:
Nice work!

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
--
Doug Peters
dpeters@bluebird-labs.com
www.bluebird-labs.com

artgodwin, 2020-12-11:
If you're updating the build can I suggest you bypass the low-current
resistor with a diode ?

This allows you to measure either low or high currents without changing the
sense resistor : you just read the high current resistor if the low-current
resistor is dropping more than 0.6V. The diode ensures you never drop too
much for the UUT to run. I think it will even work with a schottky diode
given the existing sensitivity.

May be an easy mod to the original board, too - I can't remember if the
range switching allows you to re-read if overranged.

Will the change to USB C accommodate loads with a USB C PD level of power
consumption or is it just a connector change ?

On Fri, Dec 11, 2020 at 12:42 AM Doug Peters <notifications@github.com>
wrote:

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

petersdw1, 2020-12-11:
Yes good idea on the diode. The current software release (V1.1.1) does
automatically switch back to the high current sense resistor to keep the
UUT running, but the diode fix could work well. Also the new mods will use
USB C PD for increased power delivery.

Doug

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
--
Doug Peters
dpeters@bluebird-labs.com
www.bluebird-labs.com

Closed 2020-12-11.

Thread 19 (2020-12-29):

Serial hang when using triggered capture mode

bwhanson, 2020-12-29:
When I attempt to use the triggered capture mode (not the PSU trigger enable mode) I encounter a hang in the serial communication side of things. I've attempted both on Windows and Linux to the same end, where BattLab_One_V1.1.1.py hangs waiting around for data inside `capture_profile()`, checking `if ser.in_waiting > 0` forever and never breaking the loop.

A debugger attached while we're stuck here indicates that the previous serial command (`x`) sent successfully and returned a single byte in response from the serial port, however I never appear to receive any data back from the BattLab One.

petersdw1, 2020-12-29:
Hi Bwhanson,

Can you tell me what the voltage level of your trigger event is (it should
be 3 to 5 volts)? Also can you please  check and confirm that it’s a
“clean” trigger event, meaning a clean transition from low to high. You
mentioned using BattLab_One_V1.1.1.py , but did you mean the you are using
the .exe file BattLab_One_V1.1.1. <http://BattLab_One_V1.1.1.py>exe?

Doug

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
--
Doug Peters
dpeters@bluebird-labs.com
www.bluebird-labs.com

bwhanson, 2020-12-29:
My 'scope puts the signal at 4.5v. It's a simple GPIO being fed by a level translator, and as far as rise times go we're looking at ~1us. Looks very reliable as a signal to me, but a quick screenshot is attached as well for you to confirm. The trigger signal is the blue channel 3.

I attempted both using Windows and the released .exe version, as well as a slightly modified .py development environment in Ubuntu 18.04. Using the development environment allowed me to gather that we were waiting up in this loop, whereas the .exe simply hangs and must be forced closed in Windows.
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

petersdw1, 2020-12-29:
That signal should be fine. I’m assuming the transition from high back to
low is just as clean. Are you using the PSU Trigger function to power up
the PSU when you arm the trigger? If not, could you try that? Also, can you
provide a high level idea of what you’re firmware is doing and when/where
the trigger code is being generated?

Doug

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
--
Doug Peters
dpeters@bluebird-labs.com
www.bluebird-labs.com

petersdw1, 2020-12-29:
Hi again, I probably shouldn’t assume, but are you triggering with a low to
high followed by a high to low on the GPIO pin? I ask because if you just
do a low to high start trigger without a high to low stop trigger the
BattLab-One will hang as you described.

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
--
Doug Peters
dpeters@bluebird-labs.com
www.bluebird-labs.com

bwhanson, 2020-12-29:
RE: PSU triggering. Unfortunately due to the testing I'm working on that is not possible. We're attempting to evaluate the power and performance impact of a device being addressed and used via I2C (that's the other signals in the 'scope), so we need things to be alive and stable far in advance of us beginning the test.

As far as the pulse operation goes, maybe I misunderstood the intent of the trigger setting. Should I be pulsing the GPIO in order to begin a recording of the length specified in the application, or should the GPIO be held high during the entire duration of the recording?

petersdw1, 2020-12-29:
Hi,

The normal trigger setting would look something like this in the firmware
for your DUT:

Your firmware [some setup code here]
.
.
.
Function SomeFunction () [some function you want to capture the current
profile of]
    Trigger GPIO pin High
     .
     .[function code here]
     .
     .
     Trigger GPIO pin Low
End SomeFunction

In the example above the BattLab-One will capture the current profile and
time duration of the captured function (SomeFunction) as the Active Event.

Does that make sense?

Doug

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
--
Doug Peters
dpeters@bluebird-labs.com
www.bluebird-labs.com

bwhanson, 2020-12-29:
Yep, that's how we're operating. I've tried both short and long pulses to see if there was a correlation, but there does not appear to be. Is there anything internal to the device I could gather that might help diagnosis, or anything interesting I might find in the firmware communication side of things?

petersdw1, 2020-12-29:
Just a bit more explanation, the BattLab-One handles triggering as an
interrupt in the MSP430 firmware, so if it never receives a stop High to
Low event (after a Low to High start event ) then it will just hang.

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
--
Doug Peters
dpeters@bluebird-labs.com
www.bluebird-labs.com

petersdw1, 2020-12-29:
Approximately how long would you guess the duration between start and stop
events?

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
>>> RE: PSU triggering. Unfortunately due to the testing I'm working on that
>>> is not possible. We're attempting to evaluate the power and performance
>>> impact of a device being addressed and used via I2C (that's the other
>>> signals in the 'scope), so we need things to be alive and stable far in
>>> advance of us beginning the test.
>>>
>>> As far as the pulse operation goes, maybe I misunderstood the intent of
>>> the trigger setting. Should I be pulsing the GPIO in order to begin a
>>> recording of the length specified in the application, or should the GPIO be
>>> held high during the entire duration of the recording?
>>>
>>> —
>>> You are receiving this because you commented.
>>>
>>>
>>> Reply to this email directly, view it on GitHub
>>> <https://github.com/petersdw1/Battlab-One/issues/19#issuecomment-752189534>,
>>> or unsubscribe
>>> <https://github.com/notifications/unsubscribe-auth/ABBODOMPI5V7XTLJDRMH4HDSXILZ7ANCNFSM4VM3DCLA>
>>> .
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
--
Doug Peters
dpeters@bluebird-labs.com
www.bluebird-labs.com

petersdw1, 2020-12-29:
The reason I ask is because the interrupt service routine does a count (I
think about 50uS) to debounce any false triggering events. If it falls
within that period then that may be the issue. But it sounds like you tried
longer event durations?

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
>>> Hi,
>>>
>>> The normal trigger setting would look something like this in the
>>> firmware for your DUT:
>>>
>>> Your firmware [some setup code here]
>>> .
>>> .
>>> .
>>> Function SomeFunction () [some function you want to capture the current
>>> profile of]
>>>     Trigger GPIO pin High
>>>      .
>>>      .[function code here]
>>>      .
>>>      .
>>>      Trigger GPIO pin Low
>>> End SomeFunction
>>>
>>> In the example above the BattLab-One will capture the current profile
>>> and time duration of the captured function (SomeFunction) as the Active
>>> Event.
>>>
>>> Does that make sense?
>>>
>>> Doug
>>>
>>> On Tue, Dec 29, 2020 at 12:12 PM bwhanson <notifications@github.com>
>>> wrote:
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
>>> --
>>> Doug Peters
>>> dpeters@bluebird-labs.com
>>> www.bluebird-labs.com
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
--
Doug Peters
dpeters@bluebird-labs.com
www.bluebird-labs.com

bwhanson, 2020-12-29:
Current test is 2.37s. I've tried ~1s, as well as shorter runs of 50-100ms. I don't believe I'm running into any sort of minimum length problem, although I might be on the longer end of things depending on how the interrupt-driven mode operates.

petersdw1, 2020-12-29:
Hmmm...and you’ve done a full restart (plug, unplug the BattLab-One) and
restarted the application? I know I’m grasping now....I’m also away from my
lab until Thursday so have no means to test at the moment.

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
--
Doug Peters
dpeters@bluebird-labs.com
www.bluebird-labs.com

petersdw1, 2020-12-29:
Could be also be a defective unit, have you used the other features without
the triggering? Is everything else working fine?

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
--
Doug Peters
dpeters@bluebird-labs.com
www.bluebird-labs.com

bwhanson, 2020-12-29:
And as I move parts around to replug the whole kit I discover the source of my problem, and it's of course absolutely unrelated to the BattLab - a bad BNC connector meant that the trigger was not making it to the device at all.

I should have verified that prior to opening the issue. Thank you for the help regardless!

petersdw1, 2020-12-29:
Excellent! Glad to hear it’s resolved!

Thanks and let me know how your testing goes!

Doug

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
--
Doug Peters
dpeters@bluebird-labs.com
www.bluebird-labs.com

Closed 2020-12-29.

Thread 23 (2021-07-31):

Cannot connect to BattLab-One (Windows 10)

chrisb2, 2021-07-31:
Windows 10 (ASUS Zenbook, Windows version 21H1, fully updated)
BattLab v1.2.3 (but UI shows 1.1.1 in top left)

With BattLab plugged into my laptop, in BattLab application Connect->Select COM does not show any com ports and clicking refresh makes no difference. In Device Manager it shows up under Other Devices but status says "The drivers for this device are not installed. (Code 28) There are no compatible drivers for this device.":
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
How do I fix this?

thanks,
Chris

chrisb2, 2021-08-01:
I have found I can connect to an esp32 running MicroPython OK, so seems like actual hardware is good.

chrisb2, 2021-08-01:
I got this working in the end, by uninstalling and re-installing device drivers and restarting, but not quite sure precisely what fix it!

petersdw1, 2021-08-01:
Hi Chris,

The only thing I can think of is that the driver got corrupted somehow.  I
use Zaig to install the *libusb-win32 (v1.2.6.0) *driver.

https://zadig.akeo.ie/

then install the FTDI drivers using below:

https://www.driverscloud.com/en/services/GetInformationDriver/71116-58653/ftdi-chip-cdm21228-setupzip

Let me know if that works!

Doug Peters
***@***.***
www.bluebird-labs.com
+1 (651) 272-9938

On Sat, Jul 31, 2021 at 8:18 PM Chris Borrill ***@***.***>
wrote:

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

Closed 2021-08-01.

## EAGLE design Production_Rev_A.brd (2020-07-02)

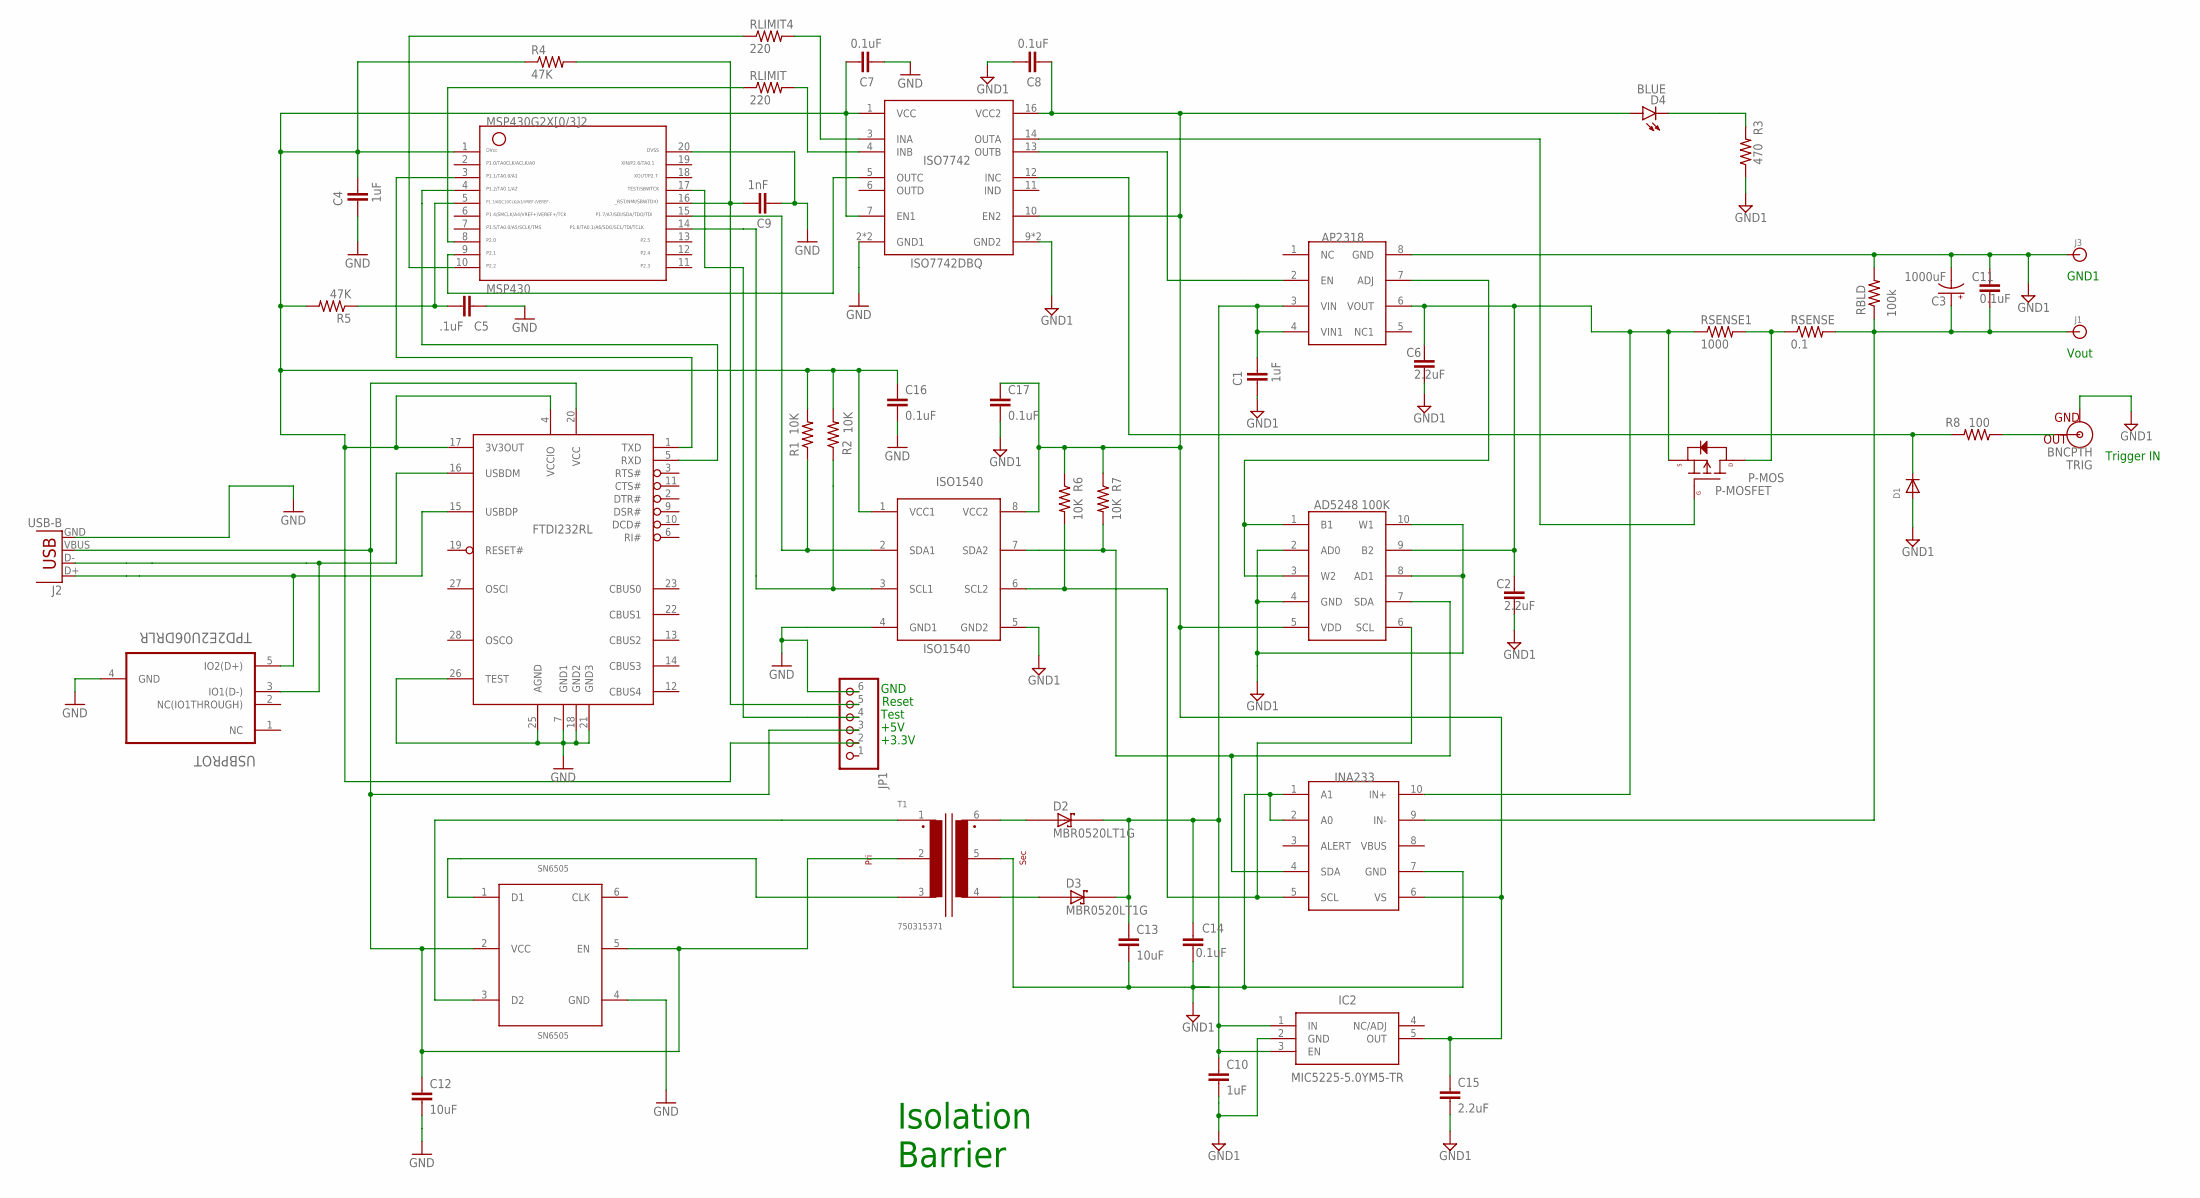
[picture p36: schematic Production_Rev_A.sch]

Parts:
AD5248: 100K; MSOP-10
AP2318: AP2318; SOIC-8
C1, C4, C10: 1uF; 1206
C2, C6, C15: 2.2uF; 1206
C3: 1000uF; PANASONIC_F
C5: .1uF; 1206
C7, C8, C11, C14, C16, C17: 0.1uF; 1206
C9: 1nF; 1206
C12, C13: 10uF; 1206
D1: DIODESOD-123; SOD-123
D2, D3: MBR0520LT1G; SOD3716X117(SOD-123)
D4: BLUE; LED-1206
FTDI232RL: FT232RL; SSOP28DB
IC2: MIC5225-5.0YM5-TR; SOT95P280X130-5N
INA233: INA233; VSSOP-10
ISO1540: ISO1540; SOIC127P600X175-8N
ISO7742: ISO7742DBQ; SOP63P599X175-16N
J1, J3: BANANA_CONN
J2: USB-B; USB-B-PTH
JP1: PINHD-1X6; 1X06
MSP430: MSP430; PW20
P-MOS: P-MOSFET; SOT23-3
R1, R2, R6, R7: 10K; 1206
R3: 470; 1206
R4, R5: 47K; 1206
R8: 100; 1206
RBLD: 100k; 1206
RLIMIT, RLIMIT4: 220; 1206
RSENSE: 0.1; 1206
RSENSE1: 1000; 1206
SN6505: SN6505; SOT95P280X145-6N
T1: 750315371; TOR-6P-HT4_SMT_6PIN_(1201)
TRIG: BNCPTH; BNC
USBPROT: TPD2E2U06DRLR; SOT50P160X60-5N

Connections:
3.3V: C4.2, C7.2, C16.1, FTDI232RL.4 (VCCIO), FTDI232RL.17 (3V3OUT), ISO1540.1 (VCC1), ISO7742.1 (VCC), ISO7742.7 (EN1), JP1.2, MSP430.1, R1.2, R2.2, R4.1, R5.2
+5V_LDO: AD5248.5 (VDD), C8.1, C15.1, C17.1, D4.A, IC2.5 (OUT), INA233.6 (VS), ISO1540.8 (VCC2), ISO7742.10 (EN2), ISO7742.16 (VCC2), R6.1, R7.1
GND: C4.1, C5.1, C7.1, C9.1, C12.2, C16.2, FTDI232RL.7 (GND1), FTDI232RL.18 (GND2), FTDI232RL.21 (GND3), FTDI232RL.25 (AGND), FTDI232RL.26 (TEST), ISO1540.4 (GND1), ISO7742.2 (GND1), ISO7742.8 (GND1), J2.GND, JP1.6, MSP430.20, SN6505.4 (GND), USBPROT.4 (GND)
GND1: AD5248.2 (AD0), AD5248.4 (GND), AD5248.8 (AD1), AD5248.10 (W1), AP2318.8 (GND), C1.1, C2.2, C3.-, C6.2, C8.2, C10.2, C11.1, C13.2, C14.2, C15.2, C17.2, D1.A, IC2.2 (GND), INA233.1 (A1), INA233.2 (A0), INA233.7 (GND), ISO1540.5 (GND2), ISO7742.9 (GND2), ISO7742.15 (GND2), J3.P$1, R3.1, RBLD.2, T1.5, TRIG.GND
LDO_EN: ISO7742.4 (INB), RLIMIT.2
LDO_EN1: MSP430.8, RLIMIT.1
LDO_EN2: AP2318.2 (EN), ISO7742.13 (OUTB)
unnamed: P-MOS.3 (D), RSENSE.1, RSENSE1.2
unnamed: AP2318.3 (VIN), AP2318.4 (VIN1), C1.2, C10.1, C13.1, C14.1, D2.1 (C), D3.1 (C), IC2.1 (IN), IC2.3 (EN)
unnamed: D3.2 (A), T1.4
unnamed: D2.2 (A), T1.6
unnamed: AD5248.1 (B1), AD5248.3 (W2), AP2318.7 (ADJ)
unnamed: D4.C, R3.2
unnamed: R8.1, TRIG.S (OUT)
NC: USBPROT.1 (NC)
RESET: C9.2, JP1.5, MSP430.16, R4.2
RS_EN: MSP430.10, RLIMIT4.1
RS_EN1: ISO7742.3 (INA), RLIMIT4.2
RS_EN2: ISO7742.14 (OUTA), P-MOS.1 (G)
SCL1: ISO1540.3 (SCL1), MSP430.14, R2.1
SCL2: AD5248.6 (SCL), INA233.5 (SCL), ISO1540.6 (SCL2), R6.2
SDA1: ISO1540.2 (SDA1), MSP430.15, R1.1
SDA2: AD5248.7 (SDA), INA233.4 (SDA), ISO1540.7 (SDA2), R7.2
TEST: JP1.4, MSP430.17
TRANS1: SN6505.3 (D2), T1.1
TRANS3: SN6505.1 (D1), T1.3
TRIGGER_MSP1: ISO7742.5 (OUTC), MSP430.9
TRIGGER_MSP2: D1.C, ISO7742.12 (INC), R8.2
UART_RX: FTDI232RL.5 (RXD), MSP430.4
UART_TX: FTDI232RL.1 (TXD), MSP430.3
USB+: FTDI232RL.15 (USBDP), J2.D+, USBPROT.5 (IO2(D+))
USB-: FTDI232RL.16 (USBDM), J2.D-, USBPROT.3 (IO1(D-))
VBUS+5V: C12.1, FTDI232RL.20 (VCC), J2.VBUS, JP1.3, SN6505.2 (VCC), SN6505.5 (EN), T1.2
VOUT: C3.+, C11.2, INA233.9 (IN-), J1.P$1, RBLD.1, RSENSE.2
VREF: C5.2, MSP430.5, R5.1
V_OUT: AD5248.9 (B2), AP2318.6 (VOUT), C2.1, C6.1, INA233.10 (IN+), P-MOS.2 (S), RSENSE1.1

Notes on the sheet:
Isolation Barrier
Test
Reset
GND
+5V
GND1
Vout
Trigger IN
+3.3V

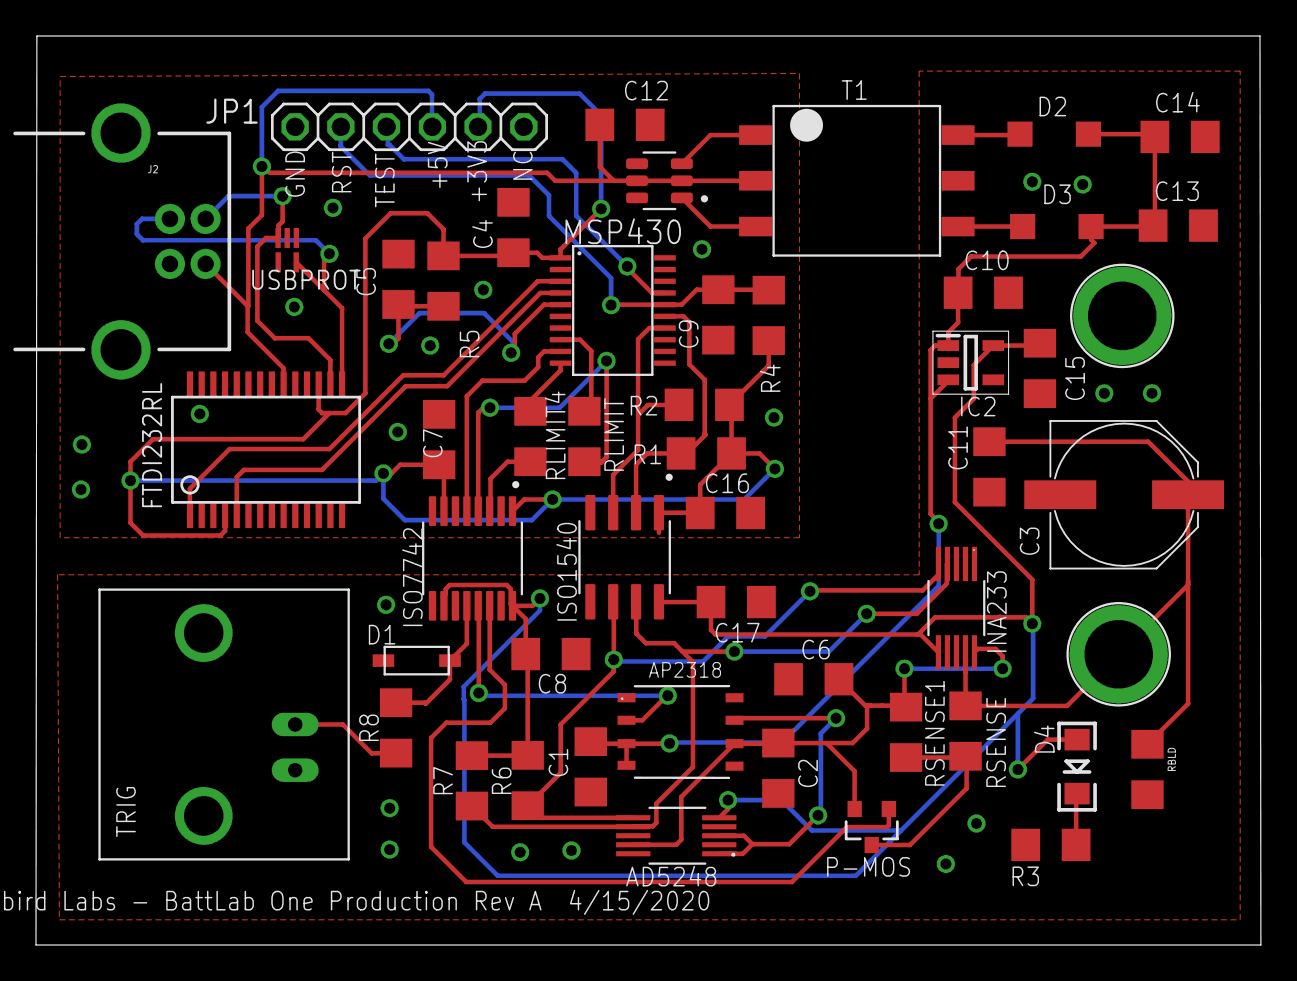
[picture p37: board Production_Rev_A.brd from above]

Board: 2 copper layers, 68.0 x 50.5 mm, 51 parts (0 on the bottom side), 35 nets.

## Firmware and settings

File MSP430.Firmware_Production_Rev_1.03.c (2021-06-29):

//******************************************************************************
//   MSP430G2xx3 based BattLab1_Pre-Release
//
//   Doug Peters
//   Bluebird Labs LLC.
//   www.bluebird-labs.com
//   February 2019
//   Built with CCS V7.0
//******************************************************************************

#include <msp430.h>
#include <stdint.h>
#include <stdbool.h>

//******************************************************************************
// #Defines ************************************************************
//******************************************************************************
//i2c Addresses
#define INA233_ADDR  0x40  //INA233
#define AD5248_ADDR  0x2c  //AD5248

#define R1_ADDR  0x80  //RDAC Resistor1 Register Addresses
#define R2_ADDR  0x00  //RDAC Resistor2 Register Addresses

//UART
#define TXD BIT2
#define RXD BIT1
#define LF 10
#define CR 13
#define MAX_BUFFER_SIZE     20

volatile char d[5];

//******************************************************************************
//INA233 Data **********************************************
//******************************************************************************
uint8_t INA233_1_D0 [2] = { 0x05,0x40 }; ///set parameters for INA233 D0h register MFR_ADC_CONFIG
uint8_t INA233_4_D0 [2] = { 0x15,0x43 }; ///set parameters for INA233 D0h register MFR_ADC_CONFIG
uint8_t INA233_16_D0 [2] = { 0x15,0x45 }; ///set parameters for INA233 D0h register MFR_ADC_CONFIG
uint8_t INA233_64_D0 [2] = { 0x15,0x47 }; ///set parameters for INA233 D0h register MFR_ADC_CONFIG


//uint8_t INA_D4 [2] = { 0x68,0x06 }; ///MFR CAL for active mode
//uint8_t INA1_D4 [2] = { 0x81,0x00 }; ///MFR CAL for sleep mode

uint8_t INA_D4 [2] = { 0x55,0x0D }; ///MFR CAL for active mode
uint8_t INA1_D4 [2] = { 0x89,0x41 }; ///MFR CAL for sleep mode


//******************************************************************************
//AD5248 Digital Potentiometer Data
//******************************************************************************

//Resistor Values for Adj Voltage Regulator
uint8_t SetR2 [1] = { 0x31};

uint8_t SetR1_1_2 [1] = { 0x19}; //1.2V
uint8_t SetR1_1_5 [1] = { 0x2B}; //1.5V
uint8_t SetR1_2_4 [1] = { 0x63}; //2.4V
uint8_t SetR1_3_0 [1] = { 0x89}; //3.0V
uint8_t SetR1_3_2 [1] = { 0x98}; //3.2V
uint8_t SetR1_3_6 [1] = { 0xAB}; //3.6V
uint8_t SetR1_3_7 [1] = { 0xB1}; //3.7V
uint8_t SetR1_4_2 [1] = { 0xD2}; //4.2V
uint8_t SetR1_4_5 [1] = { 0xE4}; //4.5V


//******************************************************************************
//Calibration Factors *********************************************
//******************************************************************************

// Active current resistor calibration
#define VERSION_MSB 0x03;
#define VERSION_LSB 0xEB;

#define CAL_12_MSB 0x01;
#define CAL_12_LSB 0x3B;

#define CAL_15_MSB 0x00;
#define CAL_15_LSB 0xE1;

#define CAL_24_MSB 0x00;
#define CAL_24_LSB 0xB5;

#define CAL_30_MSB 0x00;
#define CAL_30_LSB 0xAE;

#define CAL_32_MSB 0x00;
#define CAL_32_LSB 0xAE;

#define CAL_36_MSB 0x00;
#define CAL_36_LSB 0xAA;

#define CAL_37_MSB 0x00;
#define CAL_37_LSB 0xA8;

#define CAL_42_MSB 0x00;
#define CAL_42_LSB 0xA5;

#define CAL_45_MSB 0x00;
#define CAL_45_LSB 0xA1;

// Sleep current offset factors
#define OFFSET_12_MSB 0x00;
#define OFFSET_12_LSB 0x82;

#define OFFSET_15_MSB 0x00;
#define OFFSET_15_LSB 0xFA;

#define OFFSET_24_MSB 0x01;
#define OFFSET_24_LSB 0x04;

#define OFFSET_30_MSB 0x01;
#define OFFSET_30_LSB 0x18;

#define OFFSET_32_MSB 0x01;
#define OFFSET_32_LSB 0x18;

#define OFFSET_36_MSB 0x03;
#define OFFSET_36_LSB 0x30;

#define OFFSET_37_MSB 0x03;
#define OFFSET_37_LSB 0x34;

#define OFFSET_42_MSB 0x03;
#define OFFSET_42_LSB 0x6B;

#define OFFSET_45_MSB 0x03;
#define OFFSET_45_LSB 0xB6;


//******************************************************************************
//RDAC Data - Values for WriteReg **********************************************
//******************************************************************************
uint8_t Reg_Data [1] = { 0x00};


//******************************************************************************
// General I2C State Machine ***************************************************
//******************************************************************************

typedef enum I2C_ModeEnum{
    IDLE_MODE,
    NACK_MODE,
    TX_REG_ADDRESS_MODE,
    RX_REG_ADDRESS_MODE,
    TX_DATA_MODE,
    RX_DATA_MODE,
    SWITCH_TO_RX_MODE,
    SWITHC_TO_TX_MODE,
    TIMEOUT_MODE
} I2C_Mode;

typedef enum Transmit_ModeEnum{
    IDLE,
    TRANSMIT
} Transmit_Mode;

/* Used to track the state of the software state machine*/
I2C_Mode MasterMode = IDLE_MODE;
Transmit_Mode TXMode = IDLE;

/* The Register Address/Command to use*/
uint8_t TransmitRegAddr = 0;

/* ReceiveBuffer: Buffer used to receive data in the ISR
 * RXByteCtr: Number of bytes left to receive
 * ReceiveIndex: The index of the next byte to be received in ReceiveBuffer
 * TransmitBuffer: Buffer used to transmit data in the ISR
 * TXByteCtr: Number of bytes left to transfer
 * TransmitIndex: The index of the next byte to be transmitted in TransmitBuffer
 * */
volatile uint8_t ReceiveBuffer[MAX_BUFFER_SIZE] = {0};
volatile  uint8_t data[MAX_BUFFER_SIZE] = {0};
uint8_t RXByteCtr = 0;
uint8_t ReceiveIndex = 0;
uint8_t TransmitBuffer[MAX_BUFFER_SIZE] = {0};
uint8_t TXByteCtr = 0;
uint8_t TransmitIndex = 0;

/* I2C Write and Read Functions */

/* For slave device with dev_addr, writes the data specified in *reg_data
 *
 * dev_addr: The slave device address.
 *           Example: SLAVE_ADDR
 * reg_addr: The register or command to send to the slave.
 *           Example: CMD_TYPE_0_MASTER
 * *reg_data: The buffer to write
 *           Example: MasterType0
 * count: The length of *reg_data
 *           Example: TYPE_0_LENGTH
 *  */
I2C_Mode I2C_Master_WriteReg(uint8_t dev_addr, uint8_t reg_addr, uint8_t *reg_data, uint8_t count);

/* For slave device with dev_addr, read the data specified in slaves reg_addr.
 * The received data is available in ReceiveBuffer
 *
 * dev_addr: The slave device address.
 *           Example: SLAVE_ADDR
 * reg_addr: The register or command to send to the slave.
 *           Example: CMD_TYPE_0_SLAVE
 * count: The length of data to read
 *           Example: TYPE_0_LENGTH
 *  */
I2C_Mode I2C_Master_ReadReg(uint8_t dev_addr, uint8_t reg_addr, uint8_t count);
void CopyArray(volatile uint8_t *source, volatile uint8_t *dest, uint8_t count);

I2C_Mode I2C_Master_ReadReg(uint8_t dev_addr, uint8_t reg_addr, uint8_t count)
{
    /* Initialize state machine */
    MasterMode = TX_REG_ADDRESS_MODE;
    TransmitRegAddr = reg_addr;
    RXByteCtr = count;
    TXByteCtr = 0;
    ReceiveIndex = 0;
    TransmitIndex = 0;

    /* Initialize slave address and interrupts */
    UCB0I2CSA = dev_addr;
    IFG2 &= ~(UCB0TXIFG + UCB0RXIFG);       // Clear any pending interrupts
    IE2 &= ~UCB0RXIE;                       // Disable RX interrupt
    IE2 |= UCB0TXIE;                        // Enable TX interrupt

    UCB0CTL1 |= UCTR + UCTXSTT;             // I2C TX, start condition
    __bis_SR_register(CPUOFF + GIE);              // Enter LPM0 w/ interrupts

    return MasterMode;

}

I2C_Mode I2C_Master_WriteReg(uint8_t dev_addr, uint8_t reg_addr, uint8_t *reg_data, uint8_t count)
{
    /* Initialize state machine */
    MasterMode = TX_REG_ADDRESS_MODE;
    TransmitRegAddr = reg_addr;

    //Copy register data to TransmitBuffer
    CopyArray(reg_data, TransmitBuffer, count);

    TXByteCtr = count;
    RXByteCtr = 0;
    ReceiveIndex = 0;
    TransmitIndex = 0;

    /* Initialize slave address and interrupts */
    UCB0I2CSA = dev_addr;
    IFG2 &= ~(UCB0TXIFG + UCB0RXIFG);       // Clear any pending interrupts
    IE2 &= ~UCB0RXIE;                       // Disable RX interrupt
    IE2 |= UCB0TXIE;                        // Enable TX interrupt

    UCB0CTL1 |= UCTR + UCTXSTT;             // I2C TX, start condition
    __bis_SR_register(CPUOFF + GIE);              // Enter LPM0 w/ interrupts

    return MasterMode;
}

void CopyArray(volatile uint8_t *source, volatile uint8_t *dest, uint8_t count)
{
    uint8_t copyIndex = 0;
    for (copyIndex = 0; copyIndex < count; copyIndex++)
    {
        dest[copyIndex] = source[copyIndex];
    }
}

void uartInit(void);
void bin2bcd(unsigned int v);
void putc(unsigned char c);


//******************************************************************************
// Device Initialization *******************************************************
//******************************************************************************

void initClockTo16MHz()
{
    if (CALBC1_16MHZ==0xFF)             // 16MHz
    {
        while(1);                               // do not load, trap CPU!!
    }
    DCOCTL = 0;                               // Select lowest DCOx and MODx settings
    BCSCTL1 = CALBC1_16MHZ;                    // Set DCO
    DCOCTL = CALDCO_16MHZ;               // 16MHz
}

void initGPIO()
{
    P1SEL  |= RXD + TXD;
    P1SEL2 |= RXD + TXD;          //Assign pins 1.1 RX and 1.2 TX

    P1SEL |= BIT6 + BIT7;         // Assign I2C pins to USCI_B0
    P1SEL2|= BIT6 + BIT7;        // Assign I2C pins to USCI_B0
}

void initI2C()
{
    UCB0CTL1 |= UCSWRST;                      // Enable SW reset
    UCB0CTL0 = UCMST + UCMODE_3 + UCSYNC;     // I2C Master, synchronous mode
    UCB0CTL1 = UCSSEL_2 + UCSWRST;            // Use SMCLK, keep SW reset
    UCB0BR0 = 160;                            // fSCL = SMCLK/160 = ~100kHz
    UCB0BR1 = 0;
    UCB0I2CSA = AD5248_ADDR;                   // Slave Address
    UCB0CTL1 &= ~UCSWRST;                     // Clear SW reset, resume operation
    UCB0I2CIE |= UCNACKIE;
}

void uartInit()
{
    /*** UART Set-Up ***/
       UCA0CTL1 |= UCSSEL_2;         // SMCLK
       UCA0BR0 = 138;    // ~115200 baud
       UCA0BR1 = 0;

       UCA0MCTL = UCBRS2 + UCBRS0;        // Modulation UCBRSx = 5
       UCA0CTL1 &= ~UCSWRST;              // **Initialize USCI state machine**
       UC0IE |= UCA0TXIE;                 // Enable USCI_A0 TX interrupt
       IE2=UCA0TXIE;            // Enable USCI_A0 RX interrupt
       IE2=UCA0RXIE;            // Enable USCI_A0 RX interrupt
}

void putc(unsigned char c)
{
  while (!(IFG2 & UCA0TXIFG));
  UCA0TXBUF = c;
}

void bin2bcd(unsigned int v)
{
 unsigned int var;

 for (var = 0; var < 6; var++)
     { d[var] = v % 10;
     v=v/10; }
}

void delay_ms(unsigned int ms)
{
    while (ms)
    {
        __delay_cycles(16000);
        ms--;
    }
}

void delay(unsigned long d)
{
  unsigned long delay;
  for (delay = 0; delay < d; delay++);
}


//******************************************************************************
// Main ************************************************************************
// *****************************************************************************
//******************************************************************************

int main(void) {

     WDTCTL = WDTPW | WDTHOLD;     // Stop watchdog timer

    initClockTo16MHz();
    initGPIO();
    uartInit();                  // Initialize UART
    initI2C();

// USE Pin 2.0 for turning Voltage output ON/OFF
    P2SEL &= (~BIT0);  // Set P2.0 SEL for GPIO
    P2SEL2 &= (~BIT0); // Set P2.0 SEL for GPIO
    P2DIR |= BIT0;    // Set P2.0 as Output
    P2OUT &= (~BIT0); // Set P2.0 LOW

//Use Pin 2.1 for Trigger start
     P2IFG &= ~BIT1;    // P2.1 IFG cleared
     P2SEL &= (~BIT1);   // Set P2.1 SEL for GPIO
     P2SEL2 &= (~BIT1);  // Set P2.1 SEL for GPIO
     P2DIR &= (~BIT1);   // Set P2.1 as Input

     P2REN |= BIT1;      // Enable internal pull-up/down resistors
     P2OUT &= (~BIT1);   // Set as  pull down resistor

     P2IES &= ~BIT1;    // P2.1 LO/HI edge
     P2IFG &= ~BIT1;    // P2.1 IFG cleared
   //P2IE |= BIT1;     // P2.1 interrupt enabled
     P2IE &= (~BIT1);   // P2.1 interrupt disabled

 // USE Pin 2.2 for turning ON/OFF sleep current Sense Resistor
     P2SEL &= (~BIT2);  // Set P2.2 SEL for GPIO
     P2SEL2 &= (~BIT2); // Set P2.2 SEL for GPIO
     P2DIR |= BIT2;    // Set P2.2 as Output
     P2OUT |= BIT2; // Set P2.2 LOW - Turn Low Current Sense Resistor Off

    delay_ms(100); //Delay waiting so secondary side of power rail can power up

    I2C_Master_WriteReg(INA233_ADDR, 0xD0, INA233_4_D0, 0x02);
    I2C_Master_WriteReg(INA233_ADDR, 0xD4, INA_D4, 0x02);

  //  _BIS_SR(CPUOFF + GIE);        // Enter LPM0 w/ interrupt
    __enable_interrupt();

     while(1){

         while(TXMode == TRANSMIT){
                         I2C_Master_WriteReg(INA233_ADDR, 0xD1, Reg_Data, 0x01); //write the desired command that is to return the value
                         I2C_Master_ReadReg(INA233_ADDR, 0xD1, 2);
                        // I2C_Master_WriteReg(INA233_ADDR, 0x89, Reg_Data, 0x01); //write the desired command that is to return the value
                        // I2C_Master_ReadReg(INA233_ADDR, 0x89, 2);
                         CopyArray(ReceiveBuffer, data, 2);

                         while(!(IFG2 & UCA0TXIFG));
                         UCA0TXBUF = (char) data[1];      // 0xD1 INA233 Vshunt register MSB
                         while(!(IFG2 & UCA0TXIFG));      // 0xD1 INA233 Vshunt register LSB
                         UCA0TXBUF = (char) data[0];
                         }
    }

}


//******************************************************************************
// I2C Interrupt For Received and Transmitted Data ALSO FOR UART TX******************************
//******************************************************************************

#if defined(__TI_COMPILER_VERSION__) || defined(__IAR_SYSTEMS_ICC__)
#pragma vector = USCIAB0TX_VECTOR
__interrupt void USCIAB0TX_ISR(void)
#elif defined(__GNUC__)
void __attribute__ ((interrupt(USCIAB0TX_VECTOR))) USCIAB0TX_ISR (void)
#else
#error Compiler not supported!
#endif
{
  if (IFG2 & UCB0RXIFG)                 // Receive I2C Data Interrupt
  {
      //Must read from UCB0RXBUF
      uint8_t rx_val = UCB0RXBUF;

      if (RXByteCtr)
      {
          ReceiveBuffer[ReceiveIndex++] = rx_val;
          RXByteCtr--;
      }

      if (RXByteCtr == 1)
      {
          UCB0CTL1 |= UCTXSTP;
      }
      else if (RXByteCtr == 0)
      {
          IE2 &= ~UCB0RXIE;
          MasterMode = IDLE_MODE;
          __bic_SR_register_on_exit(CPUOFF);      // Exit LPM0
      }
  }
  else if (IFG2 & UCB0TXIFG)            // Transmit I2C Data Interrupt
  {
      switch (MasterMode)
      {
          case TX_REG_ADDRESS_MODE:
              UCB0TXBUF = TransmitRegAddr;
              if (RXByteCtr)
                  MasterMode = SWITCH_TO_RX_MODE;   // Need to start receiving now
              else
                  MasterMode = TX_DATA_MODE;
                    // Continue to transmision with the data in Transmit Buffer
              break;

          case SWITCH_TO_RX_MODE:
              IE2 |= UCB0RXIE;              // Enable RX interrupt
              IE2 &= ~UCB0TXIE;             // Disable TX interrupt
              UCB0CTL1 &= ~UCTR;            // Switch to receiver
              MasterMode = RX_DATA_MODE;    // State state is to receive data
              UCB0CTL1 |= UCTXSTT;          // Send repeated start
              if (RXByteCtr == 1)
              {
                  //Must send stop since this is the N-1 byte
                  while((UCB0CTL1 & UCTXSTT));
                  UCB0CTL1 |= UCTXSTP;      // Send stop condition
              }
              break;

          case TX_DATA_MODE:
              if (TXByteCtr)
              {
                  UCB0TXBUF = TransmitBuffer[TransmitIndex++];
                  TXByteCtr--;
              }
              else
              {
                  //Done with transmission
                  UCB0CTL1 |= UCTXSTP;     // Send stop condition
                  MasterMode = IDLE_MODE;
                  IE2 &= ~UCB0TXIE;                       // disable TX interrupt
                  __bic_SR_register_on_exit(CPUOFF);      // Exit LPM0
              }
              break;

          default:
              __no_operation();
              break;
      }

  }

      else if (IFG2 & UCA0TXIFG)            // Transmit UART Data Interrupt
      {

      }
}

//******************************************************************************
// I2C Interrupt For Start, Restart, Nack, Stop ********************************
//******************************************************************************
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

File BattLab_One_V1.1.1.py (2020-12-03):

#################################################################################
##   MSP430G2xx3 based BattLab-One Production Version 1.01
##
##   Doug Peters
##   Bluebird Labs LLC.
##   www.bluebird-labs.com
##   February 2019
##   Built with CCS V7.0
##
##   Copyright (c) 2020, Bluebird Labs LLC
##   All rights reserved.
##
##   Redistribution and use in source and binary forms, with or without
##   modification, are permitted provided that the following conditions
##   are met:
##
##   * Redistributions of source code must retain the above copyright
##     notice, this list of conditions and the following disclaimer.
##
##   * Redistributions in binary form must reproduce the above copyright
##     notice, this list of conditions and the following disclaimer in the
##     documentation and/or other materials provided with the distribution.
##
##   * Neither the name of Bluebird Labs LLC nor the names of
##     its contributors may be used to endorse or promote products derived
##     from this software without specific prior written permission.
##
##  THIS SOFTWARE IS PROVIDED BY THE COPYRIGHT HOLDERS AND CONTRIBUTORS "AS IS"
##  AND ANY EXPRESS OR IMPLIED WARRANTIES, INCLUDING, BUT NOT LIMITED TO,
##  THE IMPLIED WARRANTIES OF MERCHANTABILITY AND FITNESS FOR A PARTICULAR
##  PURPOSE ARE DISCLAIMED. IN NO EVENT SHALL THE COPYRIGHT OWNER OR
##  CONTRIBUTORS BE LIABLE FOR ANY DIRECT, INDIRECT, INCIDENTAL, SPECIAL,
##  EXEMPLARY, OR CONSEQUENTIAL DAMAGES (INCLUDING, BUT NOT LIMITED TO,
##  PROCUREMENT OF SUBSTITUTE GOODS OR SERVICES; LOSS OF USE, DATA, OR PROFITS;
##  OR BUSINESS INTERRUPTION) HOWEVER CAUSED AND ON ANY THEORY OF LIABILITY,
##  WHETHER IN CONTRACT, STRICT LIABILITY, OR TORT (INCLUDING NEGLIGENCE OR
##  OTHERWISE) ARISING IN ANY WAY OUT OF THE USE OF THIS SOFTWARE,
##  EVEN IF ADVISED OF THE POSSIBILITY OF SUCH DAMAGE.
##
#################################################################################

import tkinter as tk
from tkinter import ttk
from tkinter import *
import csv
from csv import reader
import time
import datetime
import serial
import serial.tools.list_ports
from serial.tools import list_ports
import matplotlib
from matplotlib.widgets import Cursor
import matplotlib.pyplot as plt
import platform
from tkinter import colorchooser
from tkinter import font
import os
import pkg_resources.py2_warn
from tkinter import messagebox
from tkinter import filedialog
import webbrowser

matplotlib.use('TkAgg')

#from matplotlib.backends.backend_tkagg import FigureCanvasTkAgg, NavigationToolbar2TkAgg
from matplotlib.backends.backend_tkagg import FigureCanvasTkAgg, NavigationToolbar2Tk
from matplotlib.figure import Figure

#################################################################################    
###     SETUP ROOT, FRAMES, & MATPLOTLIB CANVAS
#################################################################################

def GetIconPath():
   if platform.system() == 'Linux':
      return '@icons\\bbirdlogo.xbm'
   else:
      return 'icons\\bbirdlogo.ico'

root = tk.Tk()
root.wm_title('BattLab One Version 1.1.1')
root.resizable(False,False)
root.grid_rowconfigure(0, weight=1)
root.grid_columnconfigure(0, weight=1)

#root.iconbitmap('bbirdlogo.ico')
root.iconbitmap(GetIconPath())

s = ttk.Style() 
s.configure('TLabelframe', background='dark gray')

profile_frame = ttk.Frame(root,style='TLabelframe', width = 800, height = 600)
profile_frame.grid(row=0, column=0, padx=5,pady=(1,1),sticky = 'n')

def openBBL():
   webbrowser.open_new('http://bluebird-labs.com')

#img = PhotoImage(file='bbirdlogo_png1.png')
img = PhotoImage(file='icons\\bbirdlogo_png1.png')

logo_button = tk.Button(profile_frame,image=img,command=openBBL,state=tk.NORMAL)
logo_button.grid(row=27,column=0,rowspan=4, padx=(5,4),pady=(5,5),sticky = 'sw')

frame = ttk.Frame(profile_frame, borderwidth=5, relief='sunken', width=800, height=450)
frame.grid(row=0, column=1,  rowspan=20, padx=(3,10),pady=(1,1), sticky='n')

frame1 = ttk.Frame(profile_frame, borderwidth=5, relief='sunken', width=800, height=600)
frame1.grid(row=20, column=1, rowspan=10, padx=(10,10),pady=(5,15), sticky='e')

w = Canvas(frame, width=800, height=400)
w.config(background='black')
w.grid(row=0,column = 3,padx=5,pady=(5,5),sticky = 'n')

w1 = Canvas(frame1, width=250, height=200)
w1.config(background='black')
w1.grid(padx=5,pady=(5,5),sticky = 'nsew')

#################################################################################
###   SETUP GLOBAL VARIABLES
#################################################################################
global si,x,y,s_x,s_y,avg_active_event_I, line_color, sleep_timer,soc_file

x = []
y = []
s_x = []
s_y = []
si = []
soc = []
ocv = []
esr = []
soc_tab = []
ocv_tab = []
esr_tab = []
dc = []
dc1 = []

lo_offset=tk.DoubleVar()
lo_offset.set(0)

sleep_timer=tk.IntVar()
sleep_timer.set(1)

LSB=0.0025

line_color = StringVar()
line_color.set("blue")

line_width = DoubleVar()
line_width.set(0.5)

reading = StringVar()

CAL_12_data = StringVar()
CAL_15_data = StringVar()
CAL_24_data = StringVar()
CAL_30_data = StringVar()
CAL_36_data = StringVar()
CAL_37_data = StringVar()
CAL_42_data = StringVar()
CAL_45_data = StringVar()

Offset_12_data = StringVar()
Offset_15_data = StringVar()
Offset_24_data = StringVar()
Offset_30_data = StringVar()
Offset_36_data = StringVar()
Offset_37_data = StringVar()
Offset_42_data = StringVar()
Offset_45_data = StringVar()

sense_resistor = tk.DoubleVar()
sense_resistor.set(0.160)

sense_resistor_LO = tk.DoubleVar()
sense_resistor_LO.set(99)

data = tk.StringVar()
version = tk.StringVar()

soc_file = tk.StringVar()
soc_file.set('SOC_profiles/AA_AAA.csv')

samples= tk.IntVar()
samples.set(4)

#################################################################################
###   GET SERIAL PORT AND CONNECT
#################################################################################

baud_rate = 115200
com_port = "NONE"

def get_ports():
   ports = list(serial.tools.list_ports.comports())
   cpl = []
   for p in ports:
      cpl.append(p.device)   
   return cpl

def popupmsg(msg):
    popup = tk.Tk()
    #popup.iconbitmap('bbirdlogo.ico')
    popup.iconbitmap(GetIconPath())
    popup.wm_title("About")
    label = ttk.Label(popup, text=msg,)
    label.grid(row=0,column=0, padx=(10,10),pady= (10,10),sticky = 'nsew')
    pop_up_button = tk.Button(popup, text="Okay",command = popup.destroy,state=tk.NORMAL)
    pop_up_button.grid(row=3,column=0,padx=30,pady=(10,10),sticky = 'w')
    popup.mainloop()
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

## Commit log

2020-10-09 Minor fix re FTDI serial numbers
    Just a minor fix for crashes on short FTDI device serial numbers. I have an old custom adapter with a single digit serial number.
    [BattLab_One_V1_0_9.py]
2020-10-09 More reliable way to get device name
    The grep doesn't always select the correct entry in list_ports if there are multiple with the same VID:PID.
    Only verified to work on Windows, but I'd expect pyserial device name handling to be pretty cross platform.
    [BattLab_One_V1_0_9.py]
2020-12-12 Add 3D printable enclosure (#17)
    [BattLab_One_Enclosure_bottom.stl, BattLab_One_Enclosure_top-logo.stl, BattLab_One_Enclosure_top.stl]

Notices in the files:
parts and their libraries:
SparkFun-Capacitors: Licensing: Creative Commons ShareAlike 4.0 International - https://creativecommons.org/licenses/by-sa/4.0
